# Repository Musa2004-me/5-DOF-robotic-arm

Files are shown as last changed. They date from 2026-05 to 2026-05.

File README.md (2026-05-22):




https://github.com/user-attachments/assets/d4726c3b-9be9-457d-948b-c11e2f1f0353



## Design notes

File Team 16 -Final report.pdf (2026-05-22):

# AIN SHAMS UNIVERSITY-FACULTY OF ENGINEERING

# [MCT343]

# Mechatronic System Design

# Final Submission Report

# Team 16

Name | ID | Section
Abdullah Mahmoud Abdelkarim | 2100658 | 1 MCT
Abdelkarim Wael Abdelkarim | 2101733 | 1 MCT
Mohamed Islam Salah Aldin Bodour | 2101439 | 1 MCT
Musa Gamal El-Shenawy | 2100614 | 1 MCT
Zeyad Samer Lotfy | 2100820 | 1 MCT

# Provided to:

# Mohamed Nabil Mohamed Mohamed (https://eng.asu.edu.eg/staff/m.nabil) Nansy Emad Mohamed Elhady (https://eng.asu.edu.eg/staff/nancy_emad)

# Contribution Sheet

Name | Contribution
Abdullah Mahmoud Abdelkarim | Actuator Sizing PID Design
Abdelkarim Wael Abdelkarim | Control Design PID Stress Analysis
Mohamed Islam Salah Aldin Bodour | Machine vision Design Report
Musa Gamal El-Shenawy | Design Report Simulation Actuator Sizing
Zeyad Samer Lotfy | Control Design PID

# Table of Contents

# Table of Figueres

# Introduction

In modern industrial automation, the need for efficient and accurate inspection systems has become very important to ensure high-quality standards. In line with this demand, a 5 Degree of Freedom (DOF) robotic arm has been designed and developed with the primary purpose of scanning products and detecting defects through QR code identification. This system is engineered to enhance the speed and reliability of product inspection processes, minimizing human error and increasing production efficiency.
The robot features five revolute joints, allowing it to achieve flexible and precise movements necessary to navigate various inspection points. Equipped with a high-resolution camera, the robotic arm locates and scans QR codes placed on different sections of the product. Each QR code contains essential data regarding the product's status, including defect information, manufacturing details, and quality control metrics. By decoding these QR codes, the robot swiftly determines if defects are present, categorizes the type of defect, and logs the inspection results for further processing.
The system is designed to operate seamlessly within industrial environments, capable of integrating with conveyor systems or stationary product lines. Its efficient path planning and real-time decision-making allow for rapid inspections, enhancing overall productivity. Furthermore, the robotic arm is programmed with advanced kinematic control, enabling it to reach complex product orientations with high accuracy.

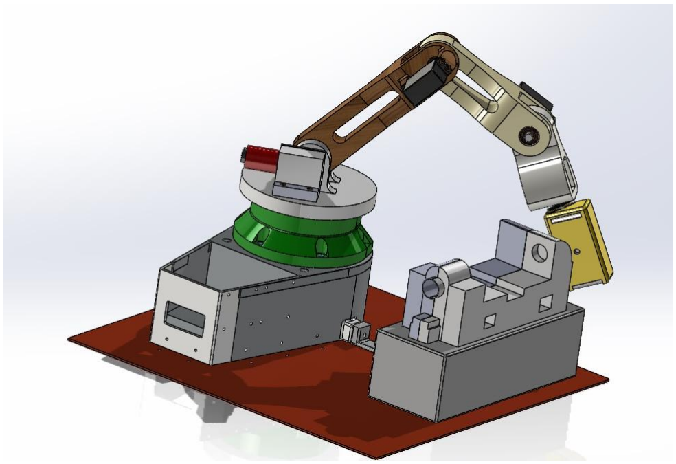
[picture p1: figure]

## Figure 1 5DOF Robotic Arm

# Design methodology and requirements analysis:

# We consider several parameters in our robotic arm:

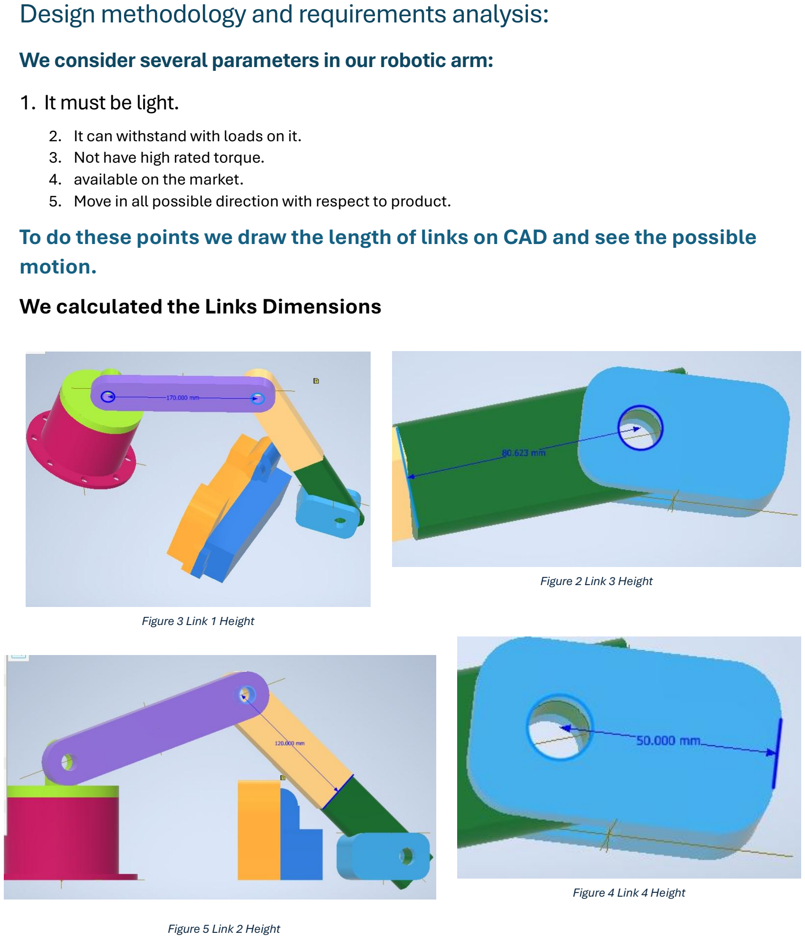
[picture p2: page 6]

1. It must be light.
2. It can withstand with loads on it.
3. Not have high rated torque.
4. available on the market.
5. Move in all possible direction with respect to product.

# To do these points we draw the length of links on CAD and see the possible

motion.

# We calculated the Links Dimensions

## Figure 3 Link 1 Height

## Figure 5 Link 2 Height

## Figure 2 Link 3 Height

## Figure 4 Link 4 Height

# Mechanical design specifications and CAD drawings

# Working Drawing:-

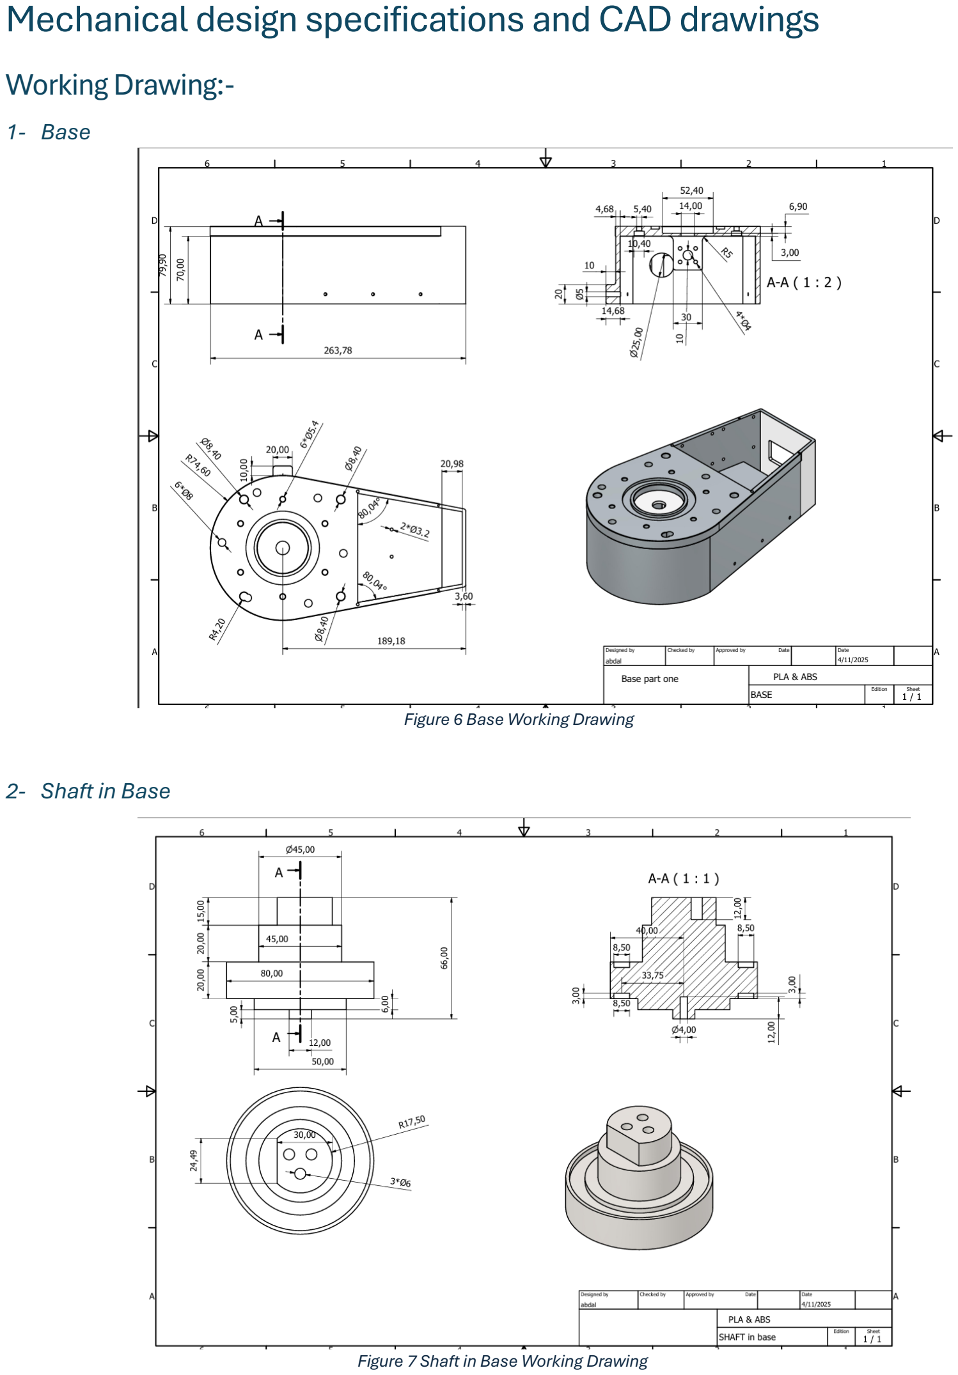
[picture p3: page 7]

# 1- Base

# 2- Shaft in Base

## Figure 6 Base Working Drawing

## Figure 7 Shaft in Base Working Drawing

# 3- Rotating Plate

# 4- Housing

## Figure 8 Rotating Plate Working Drawing

## Figure 9 Housing Working Drawing

# 5- Link 1

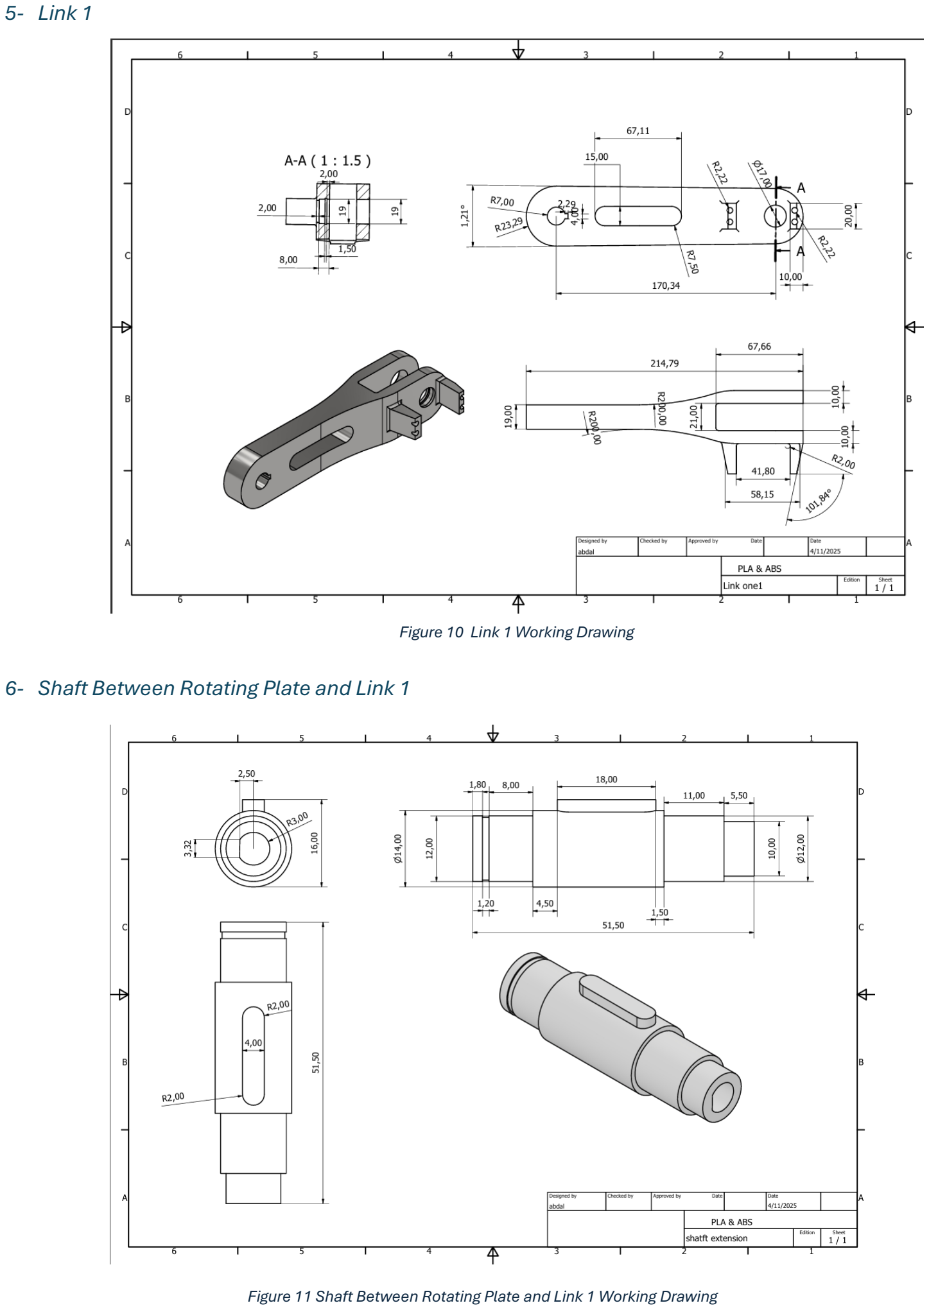
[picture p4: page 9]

# 6- Shaft Between Rotating Plate and Link 1

## Figure 10 Link 1 Working Drawing

## Figure 11 Shaft Between Rotating Plate and Link 1 Working Drawing

# 7- Link 2

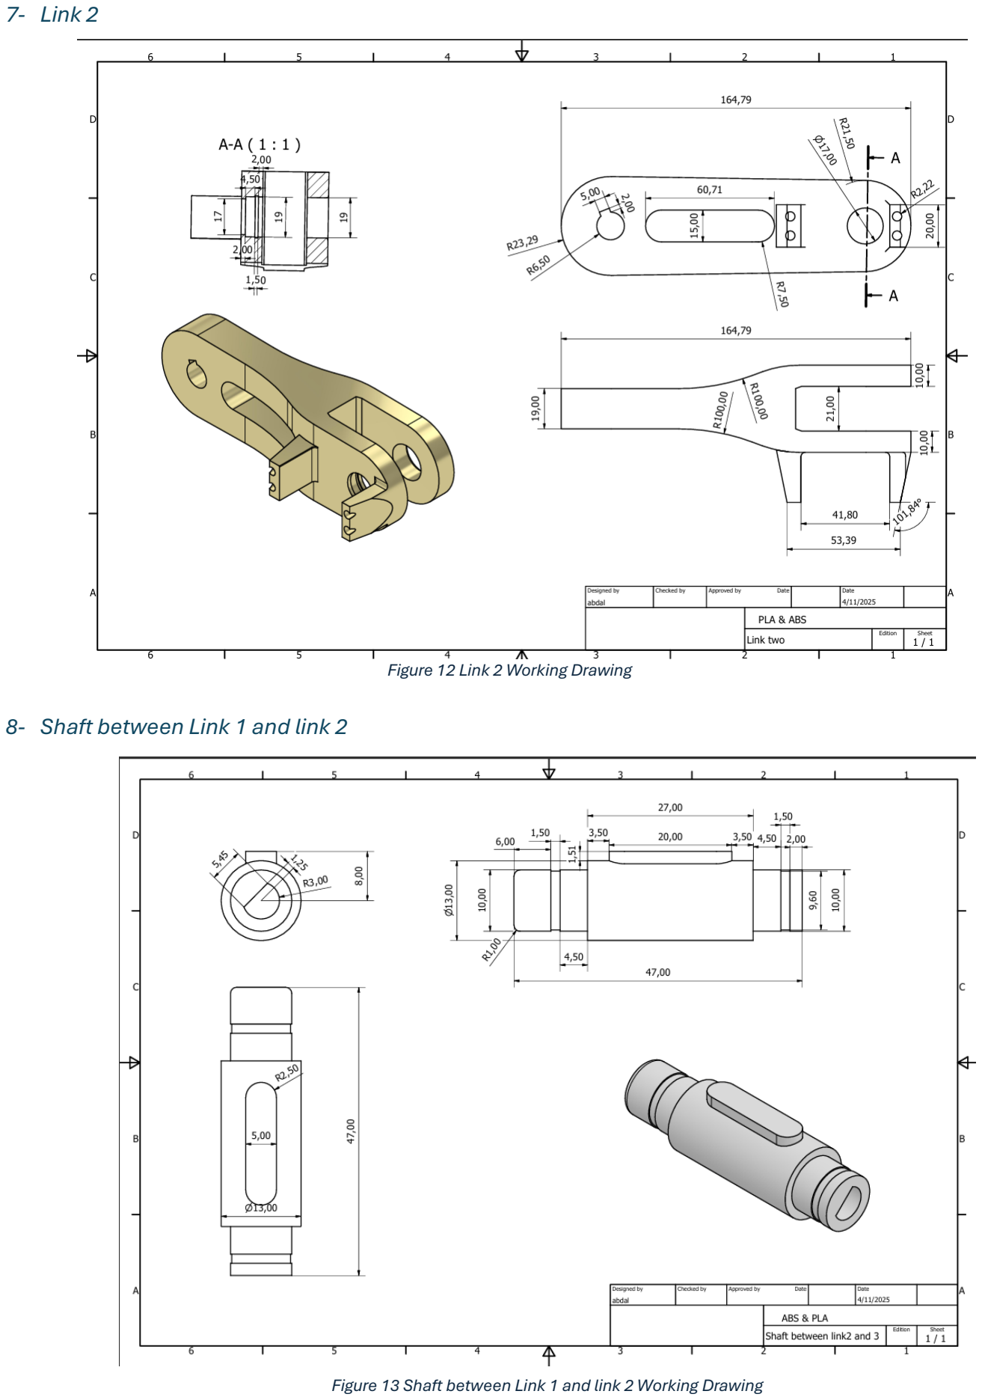
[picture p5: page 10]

# 8- Shaft between Link 1 and link 2

## Figure 12 Link 2 Working Drawing

## Figure 13 Shaft between Link 1 and link 2 Working Drawing

# 9- Link 3

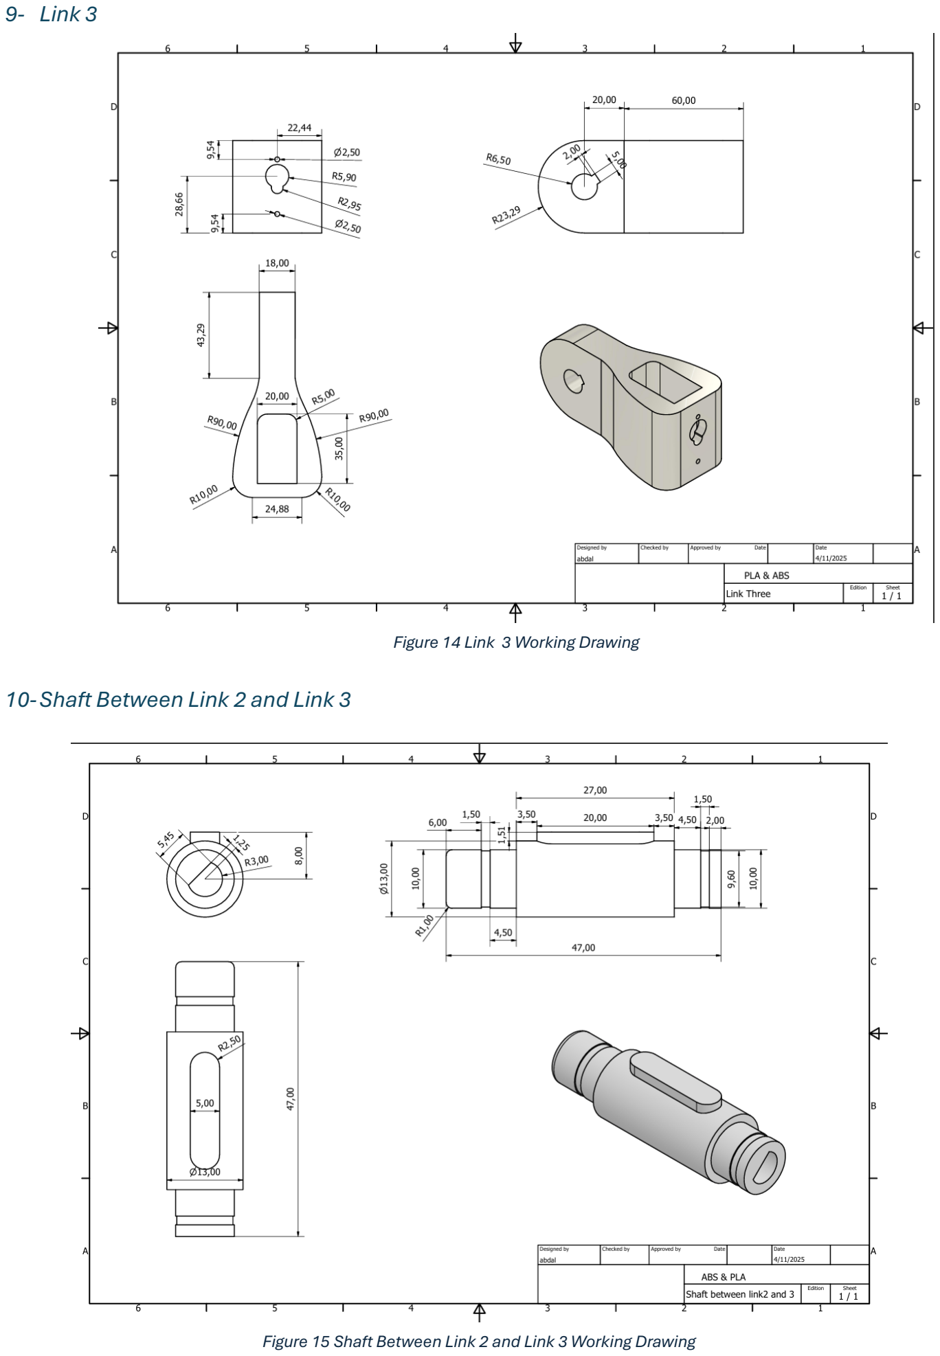
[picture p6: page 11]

# 10-Shaft Between Link 2 and Link 3

## Figure 14 Link 3 Working Drawing

## Figure 15 Shaft Between Link 2 and Link 3 Working Drawing

# 11-Camera Holder

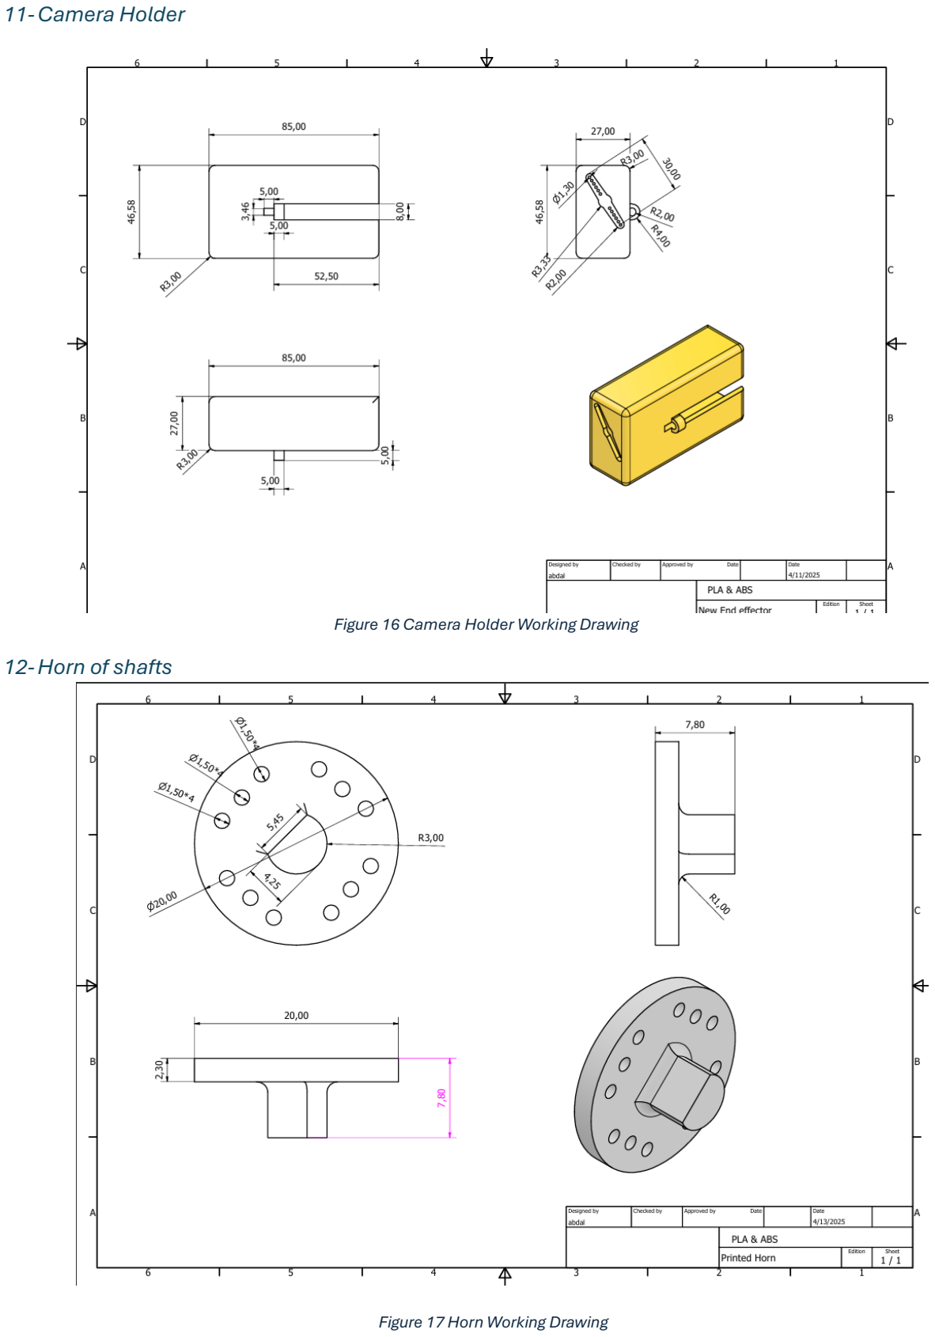
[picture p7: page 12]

# 12-Horn of shafts

## Figure 16 Camera Holder Working Drawing

## Figure 17 Horn Working Drawing

# Product

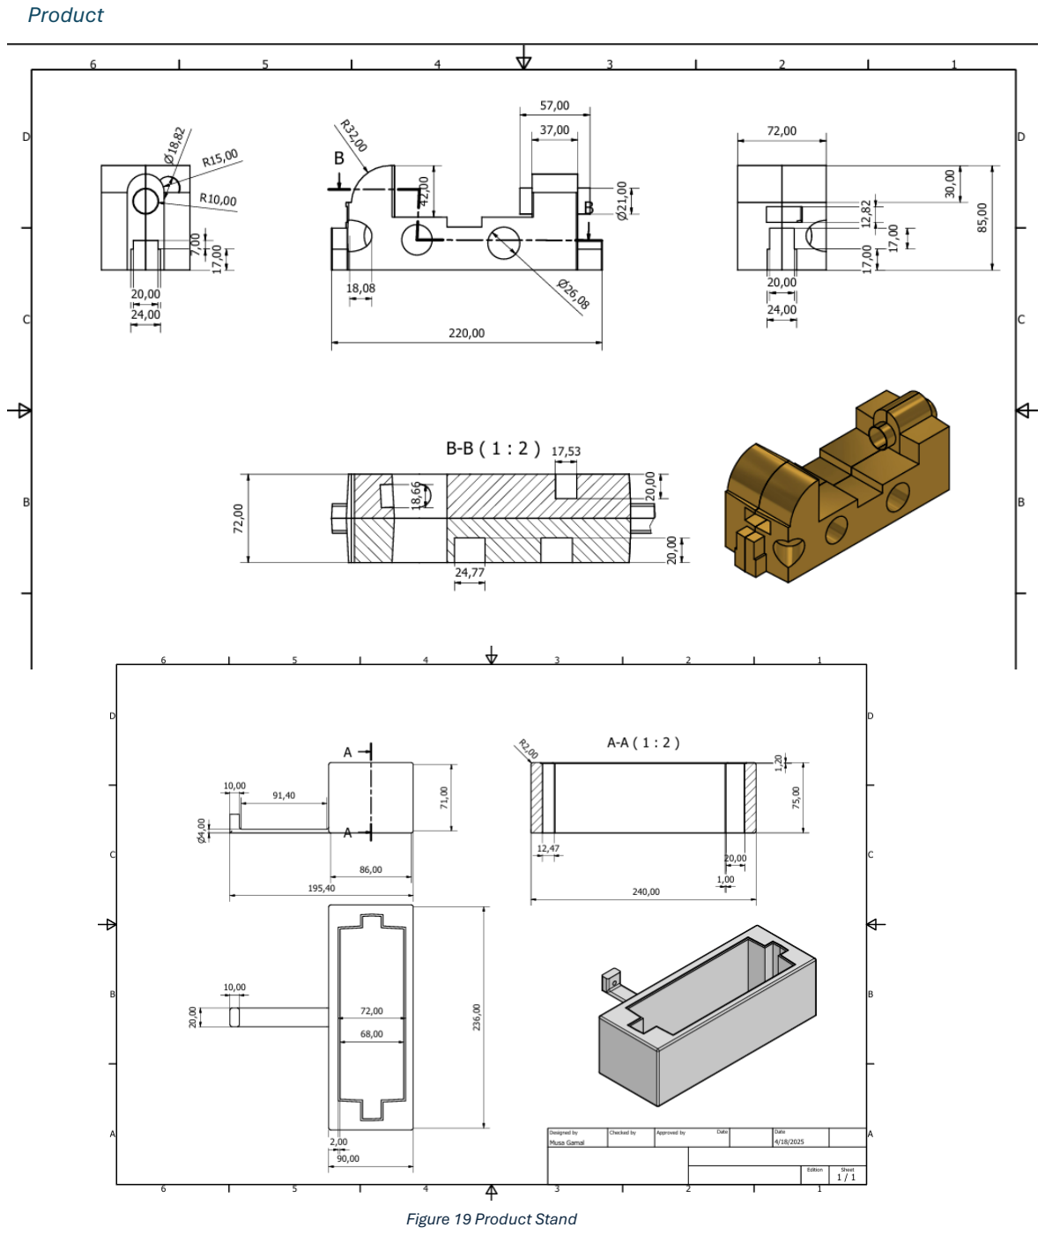
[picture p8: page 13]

# Product Stand

## Figure 18 Product Working Drawing

## Figure 19 Product Stand

# Assembly

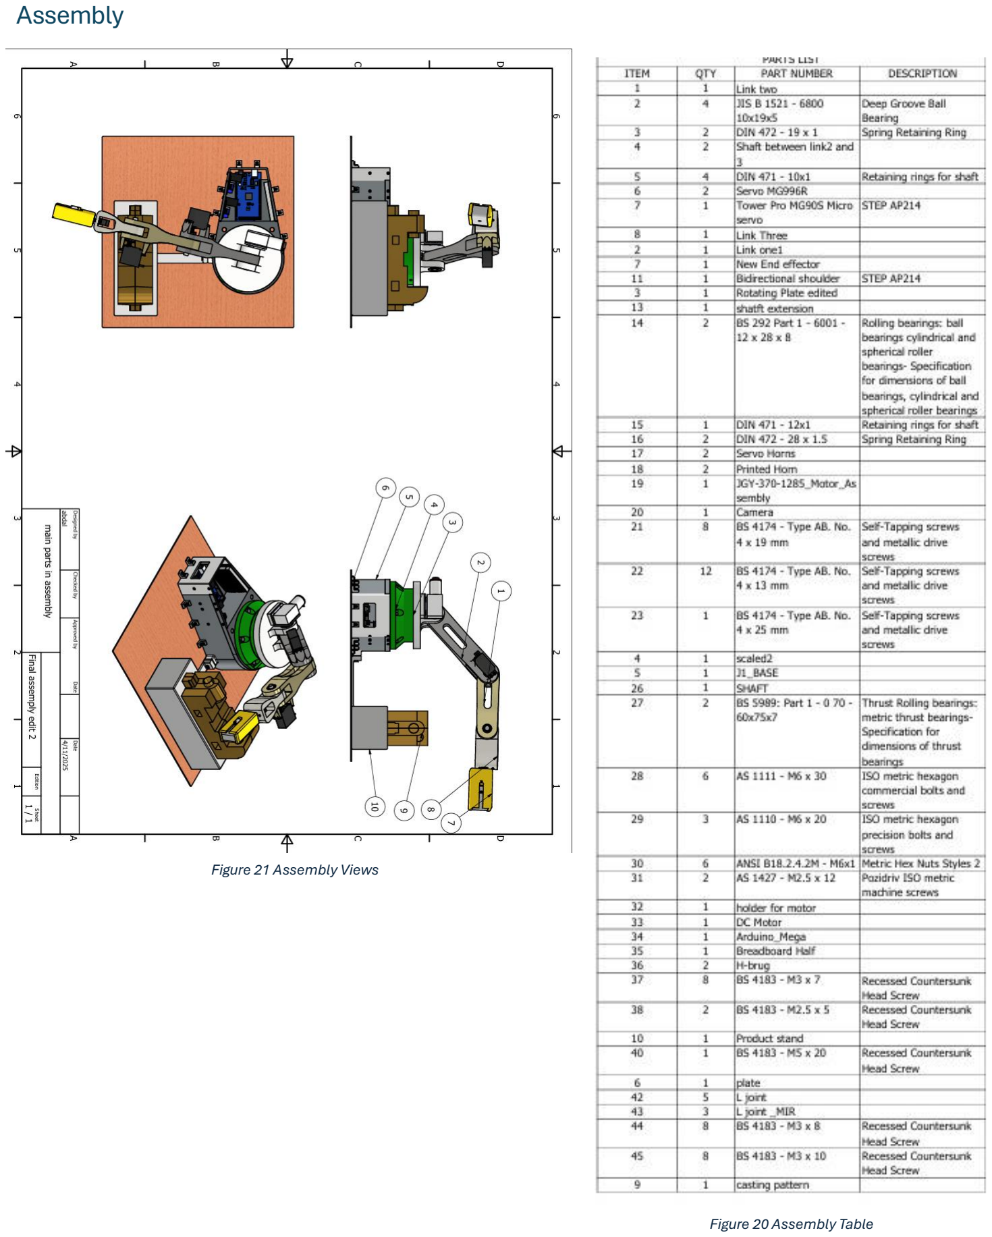
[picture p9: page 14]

## Figure 21 Assembly Views

## Figure 20 Assembly Table

# Links Connection

# Rotating plate & link 1 Connection

# Rotating plate & Base Connection

## Figure 22 Rotating plate & link 1 Connection

## Figure 23 Rotating plate & Base Connection

# Link 1 & link 2 Connection

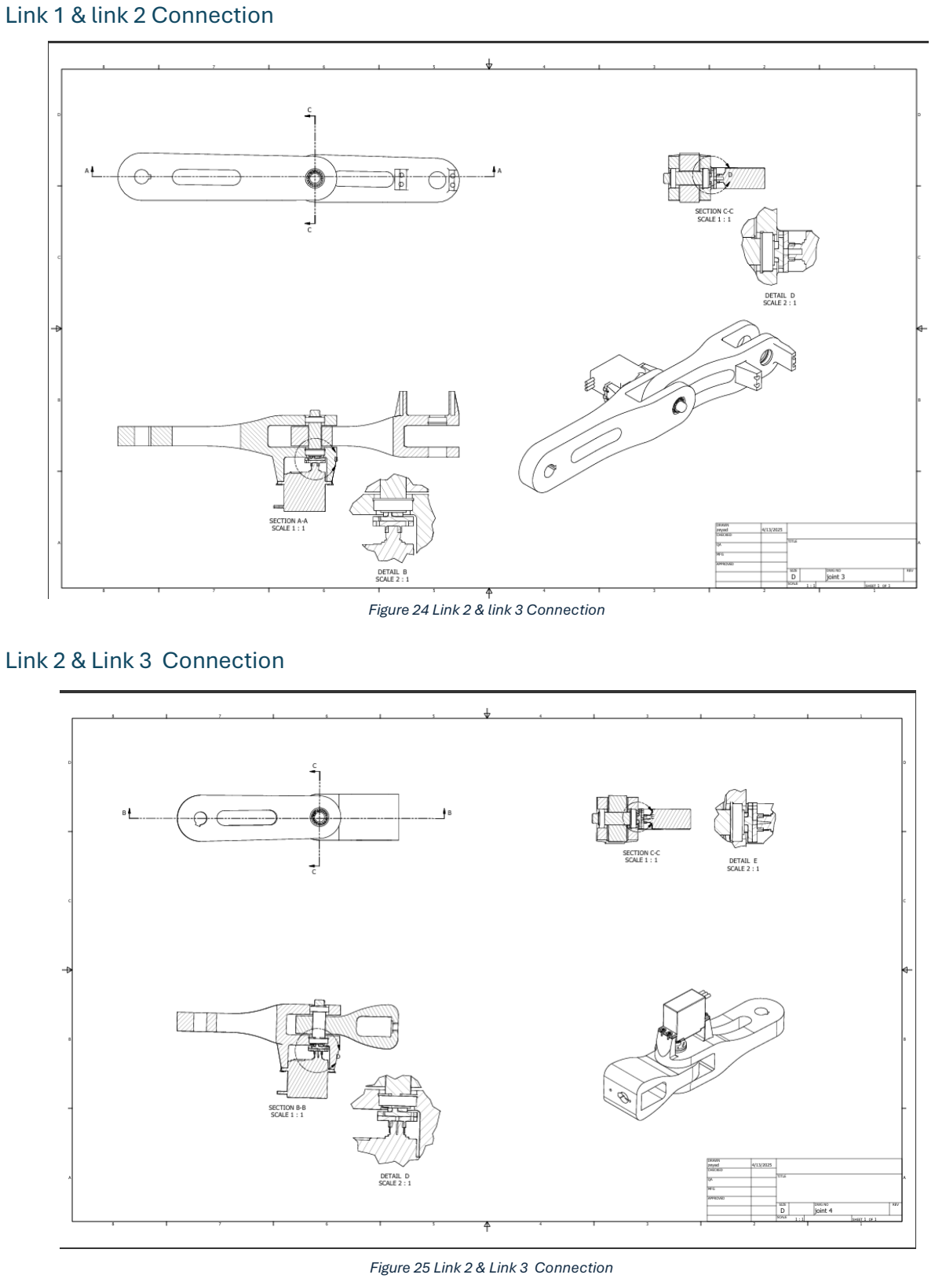
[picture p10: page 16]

# Link 2 & Link 3 Connection

## Figure 24 Link 2 & link 3 Connection

## Figure 25 Link 2 & Link 3 Connection

# Link 3 and camera holder Connection

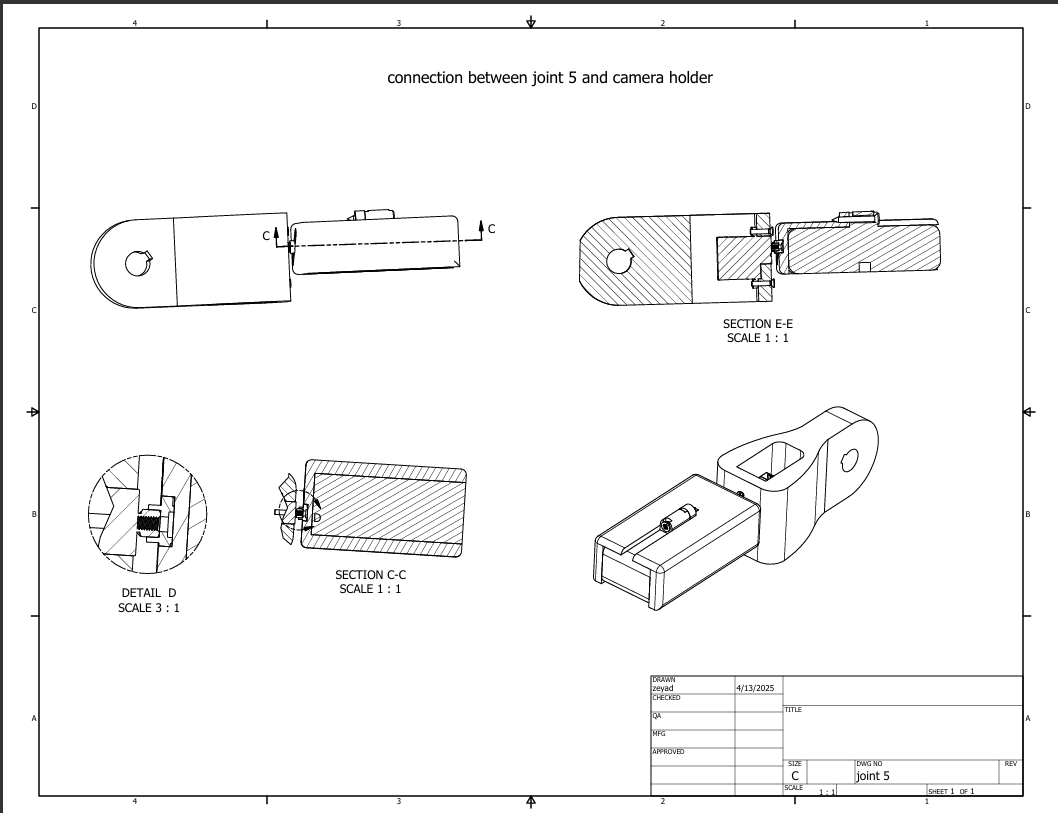
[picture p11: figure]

# Standard Parts :-

# 1) Bearing

# - 5989 thrust Bearing 60x75x7 - 6800 Ball Bearing 10x19x5 - 6001 Deep Groove Ball Bearing 12x28x8

# 2) Snap Ring

# - DIN 472 28x1.5 - DIN 472 19x1 - DIN 471 12x1 - DIN 471 10x1

# 3) Servo Horn, Bidirctional Arm of Servo

# 4) M3,M4,M5,M6,M8 Through Bolts

## Figure 26 Link 3 and camera holder Connection

# Stress Analysis:-

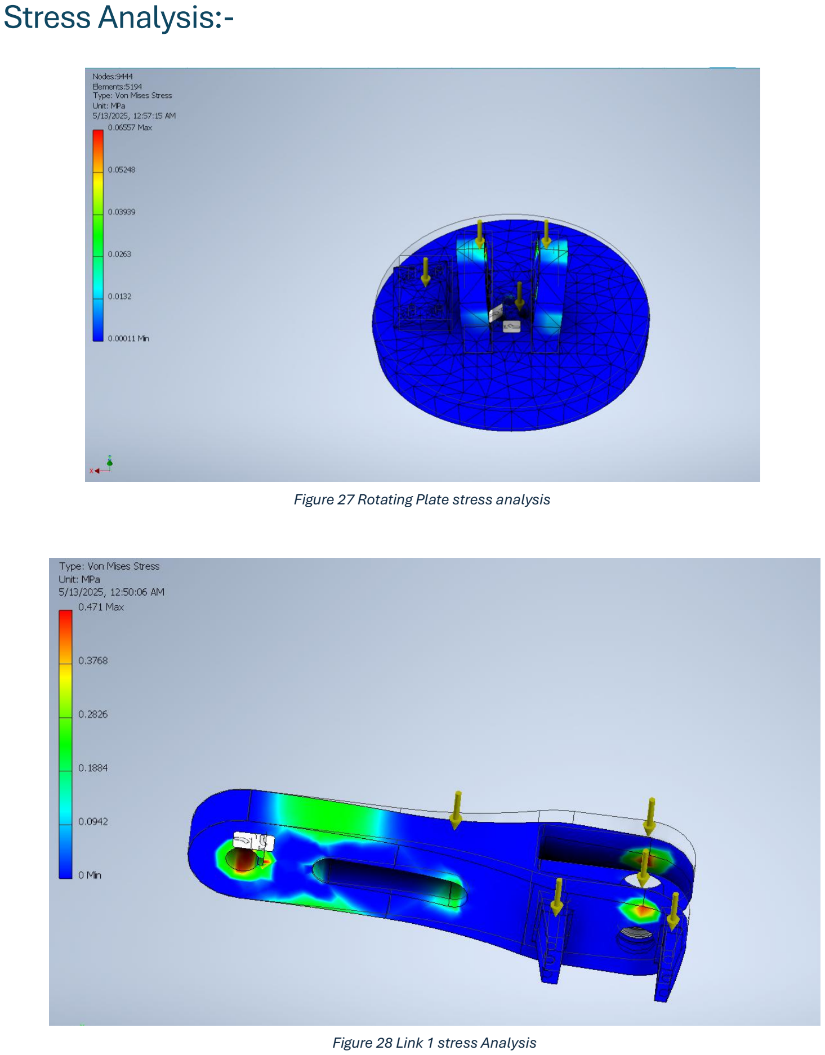
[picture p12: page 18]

## Figure 28 Link 1 stress Analysis

## Figure 27 Rotating Plate stress analysis

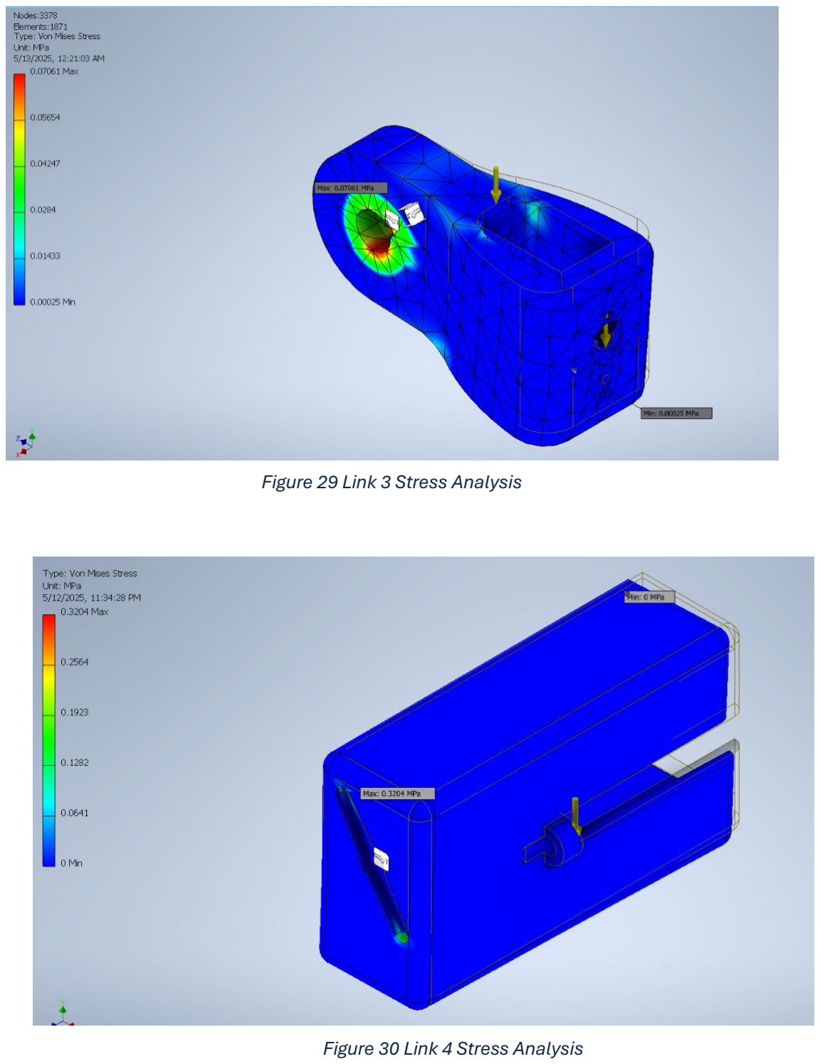
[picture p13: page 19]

## Figure 29 Link 3 Stress Analysis

## Figure 30 Link 4 Stress Analysis

# Shafts

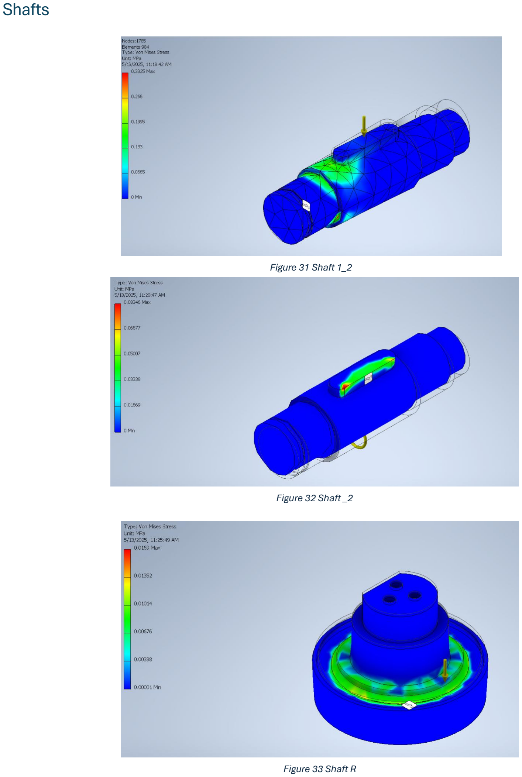
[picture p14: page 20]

## Figure 31 Shaft 1_2

## Figure 32 Shaft _2

## Figure 33 Shaft R

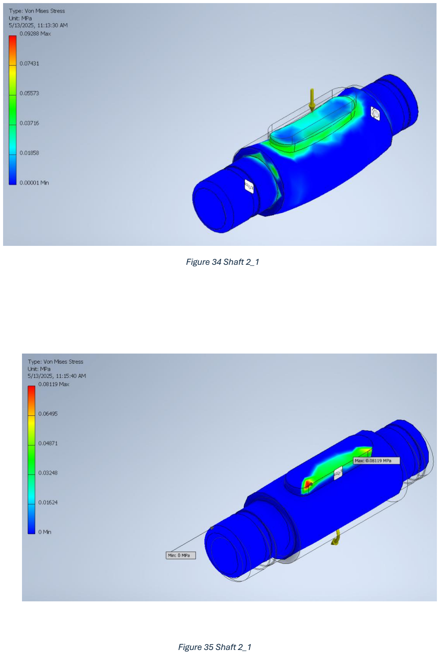
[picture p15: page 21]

## Figure 34 Shaft 2_1

## Figure 35 Shaft 2_1

## Figure 36 Shaft2_3

## Figure 37 Shaft2_3

# Actuator Sizing

# MATLAB-Simulink Model

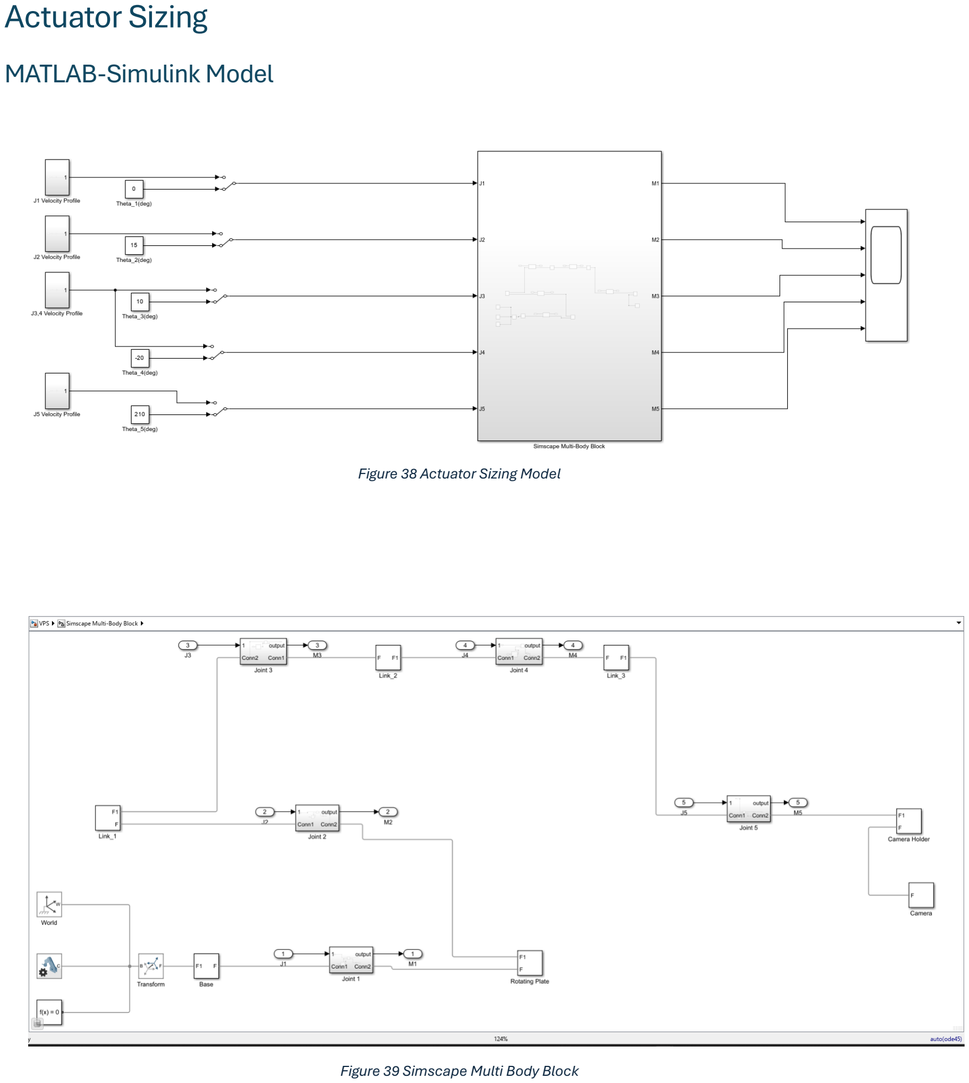
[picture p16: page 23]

## Figure 38 Actuator Sizing Model

## Figure 39 Simscape Multi Body Block

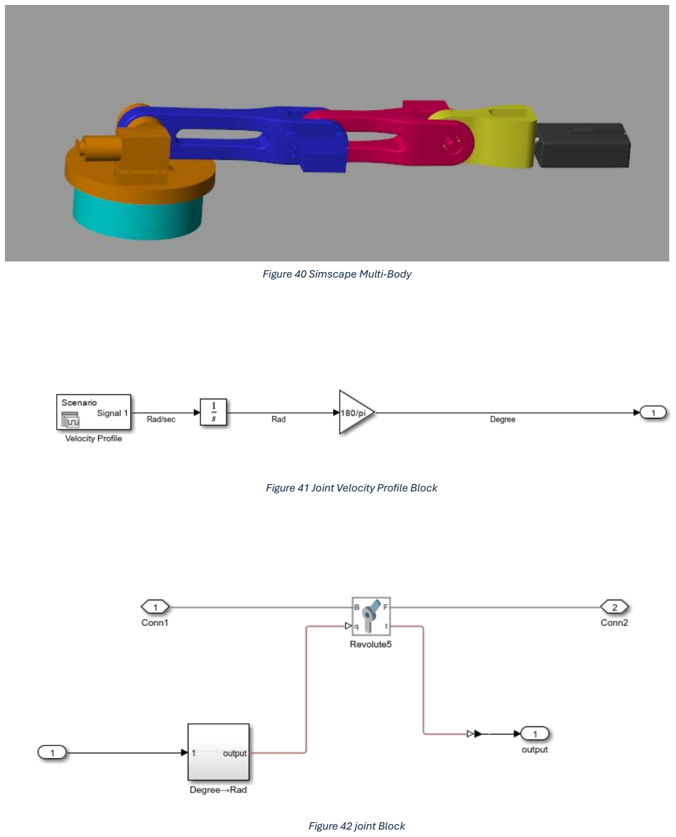
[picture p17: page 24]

## Figure 40 Simscape Multi-Body

## Figure 41 Joint Velocity Profile Block

## Figure 42 joint Block

# Actuator Torque on:-

# Joint 1

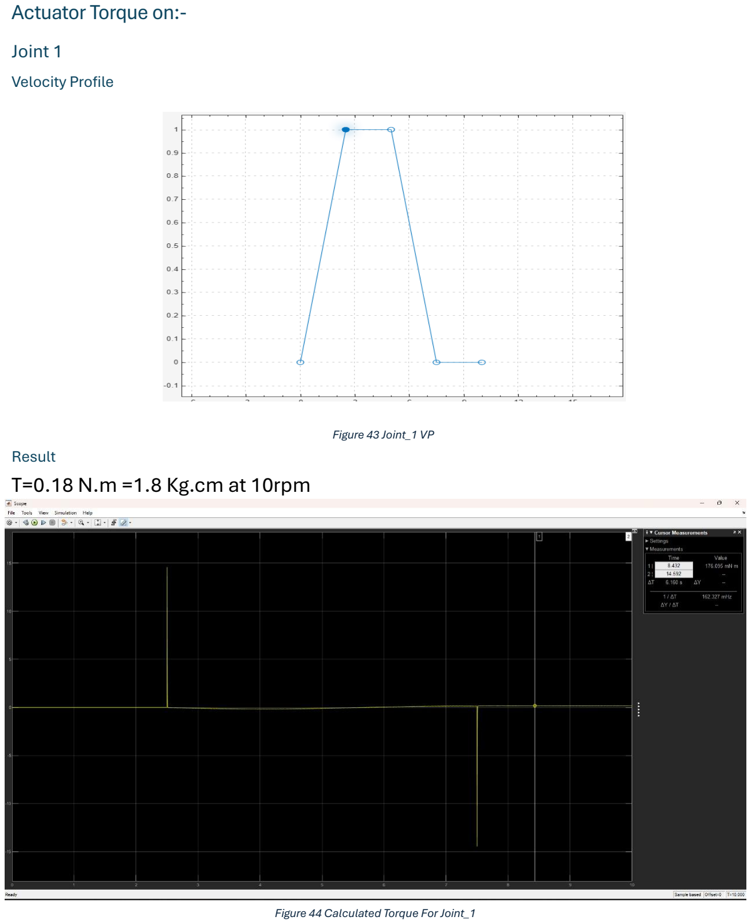
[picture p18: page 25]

# Velocity Profile

# Result

# T=0.18 N.m =1.8 Kg.cm at 10rpm

## Figure 43 Joint_1 VP

## Figure 44 Calculated Torque For Joint_1

# Joint 2

# Velocity Profile

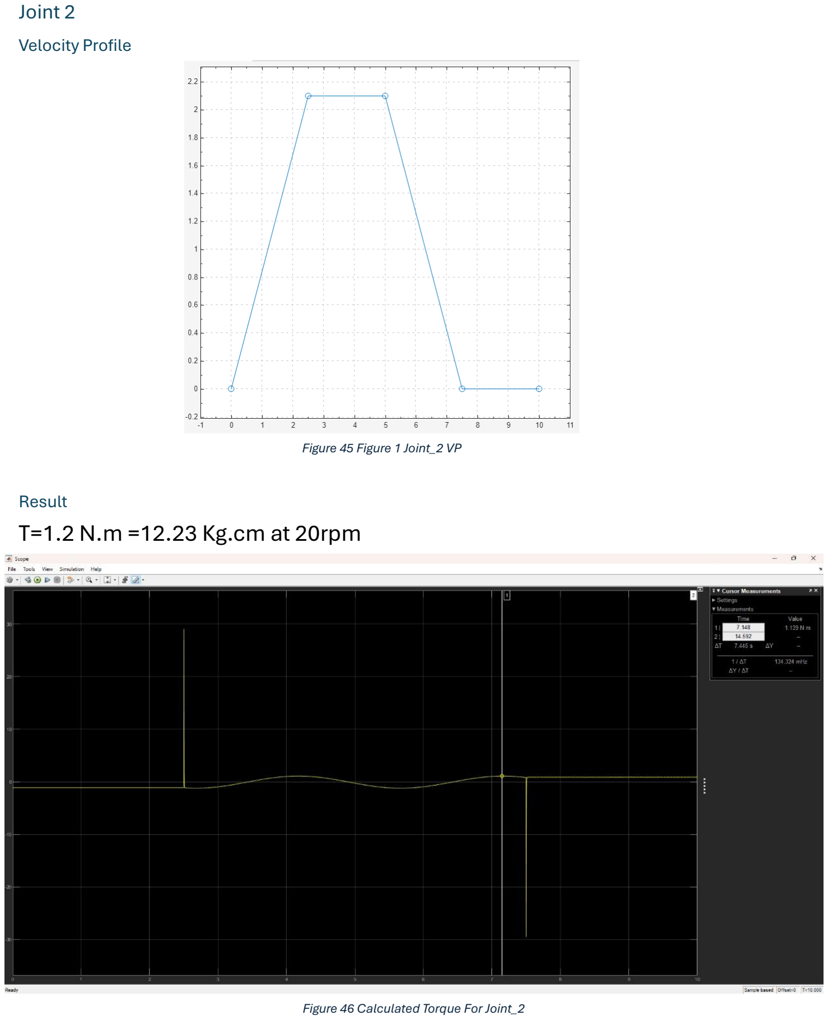
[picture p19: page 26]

# Result

# T=1.2 N.m =12.23 Kg.cm at 20rpm

## Figure 46 Calculated Torque For Joint_2

## Figure 45 Figure 1 Joint_2 VP

# Joint 3

# Velocity Profile

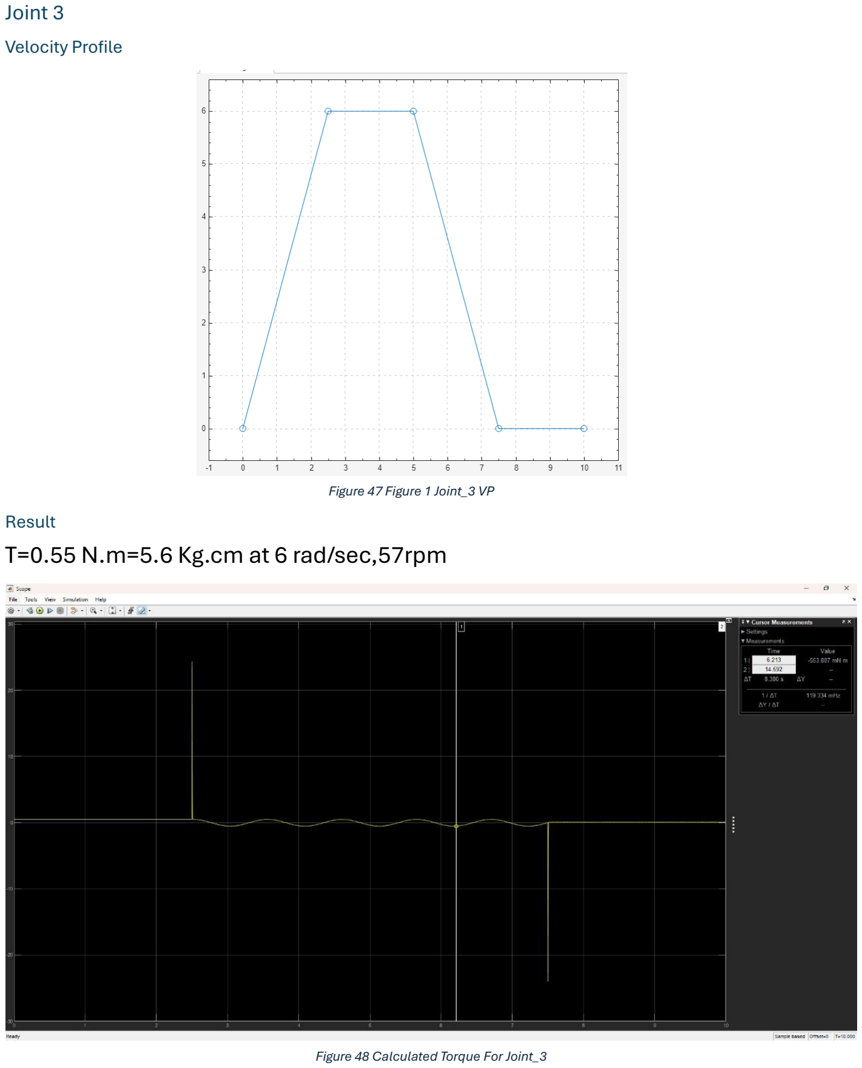
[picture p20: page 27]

# Result

# T=0.55 N.m=5.6 Kg.cm at 6 rad/sec,57rpm

## Figure 48 Calculated Torque For Joint_3

## Figure 47 Figure 1 Joint_3 VP

# Joint 4

# Velocity Profile

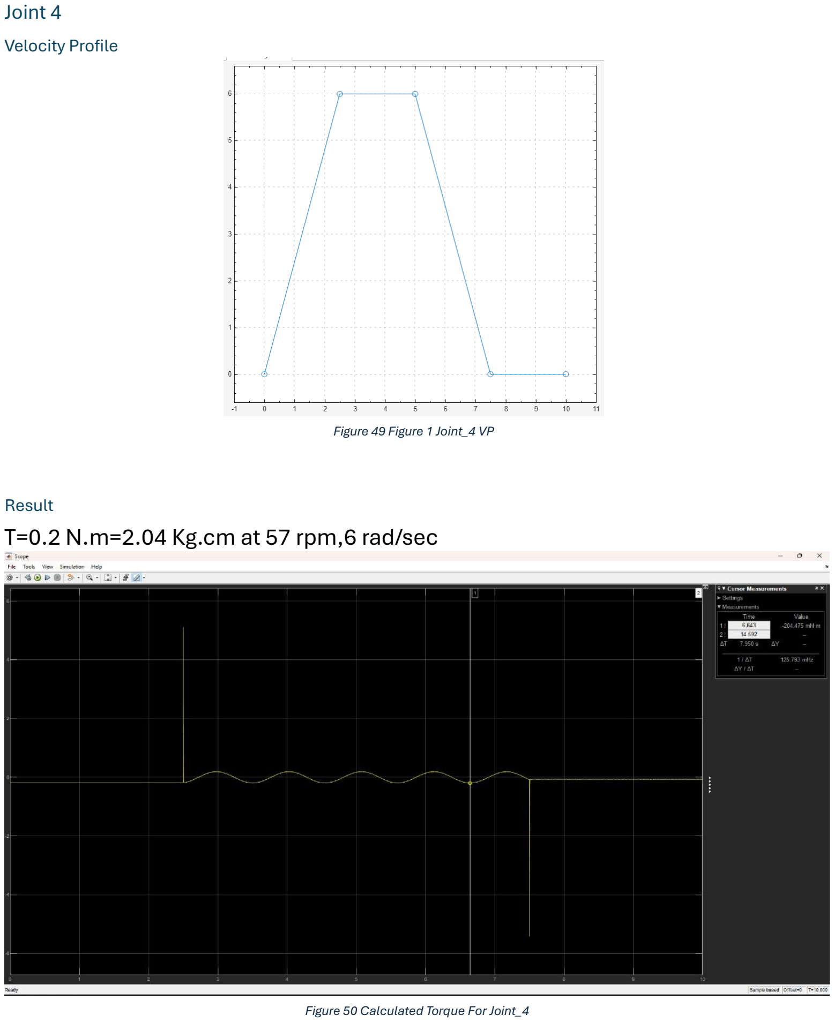
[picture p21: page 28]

# Result

# T=0.2 N.m=2.04 Kg.cm at 57 rpm,6 rad/sec

## Figure 50 Calculated Torque For Joint_4

## Figure 49 Figure 1 Joint_4 VP

# Joint 5

# Velocity Profile

# Result

# T= 0.0075N.m =0.076 Kg.cm at 10rad/sec,95.5 rpm

## Figure 52 Calculated Torque For Joint_5

## Figure 51 Figure 1 Joint_5 VP

# Actuator Selection:-

Joint | Actuator Torque(T)(Kg.cm) | Available Torque(Kg.cm) | Motor Type
1 | 1.8 | 4.4 | 25GA370 DC Gear Motor With Encoder
2 | 12.23 | 12.5 | JGY-370 DC Geared Motor With Encoder
3 | 5.6 | 10 | MG995 Servo Motor 180°
4 | 2.04 | 10 | MG996 Servo Motor 180°
5 | 0.075 | 3.2 | S3003 Servo Motor 270 Degree

# Electronics and control system documentation

This circuit is designed to control multiple motors and servos using an Arduino Mega 2560 microcontroller. It includes JGY-370 And JGA25-371 DC Geared motors with encoders, two MG996R servos, one MG90S servo, and an L298N motor driver. Power is supplied by a 12V adapter OR a 12V lithium-ion battery. A LM7805 MOSFET is used to control the power to the motor driver.

# Microcontroller Integration and Circuit Schematics

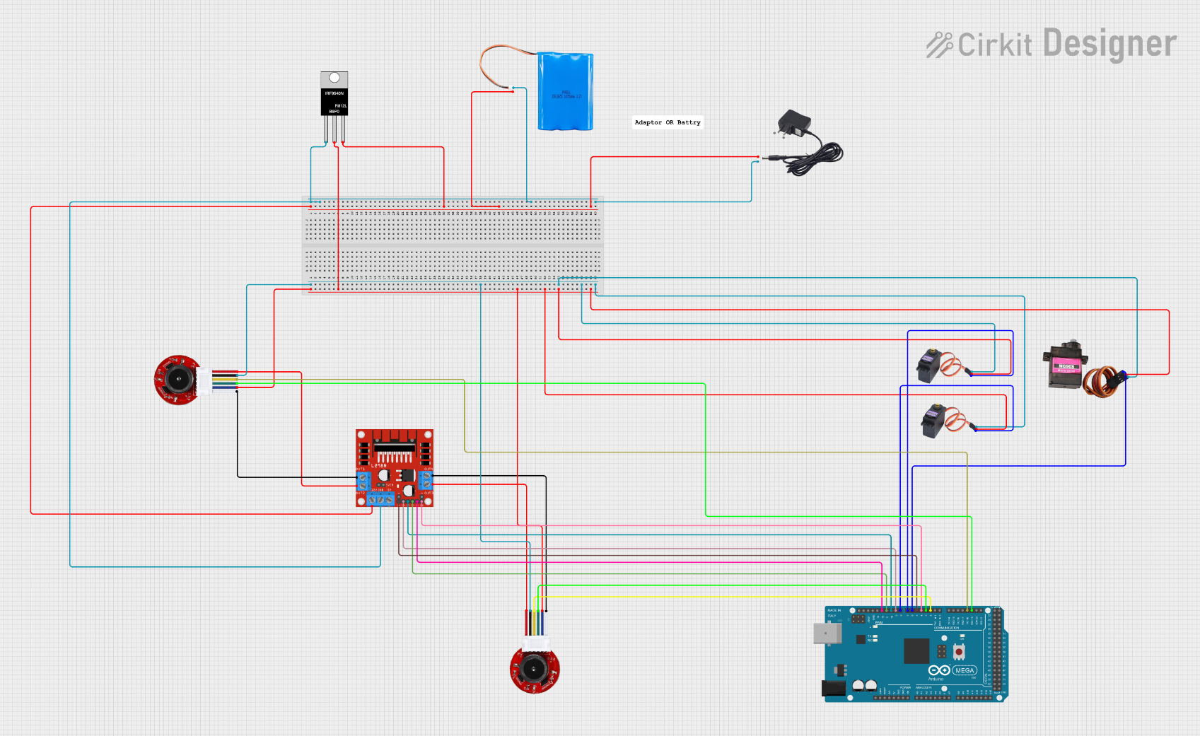
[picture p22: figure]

# FULL PIN MAPPING SUMMARY

Device | Arduino Pin
Motor A IN1/IN2 | D9, D10
Motor B IN3/IN4 | D11, D12
ENA/ENB (PWM) | D5, D4
Encoder A (motor A) | D2 (INT)
Encoder B (motor A) | D3
Encoder A (motor B) | D18 (INT)
Encoder B (motor B) | D19
Servo MG996R #1 | D6
Servo MG996R #2 | D7
Servo MG90S | D8

## Figure 53 Robot Motion Control System Circuit

# Hint:

# We use cytron MDD3A motor driver as we need linear

voltage to PWM relation and more delivered current.

# Battery Sizing

# Estimate Power Consumption

Component | Voltage (V) | Current (A) | Power (W) = V × I
25GA370 DC Gear Motor w/ Encoder | 12 | 1.2 | 14.4
JGY-370 DC Gear Motor w/ Encoder | 12 | 1.5 | 18
MG995 Servo Motor (180°) | 5 | 1 | 5
MG996 Servo Motor (180°) | 5 | 1 | 5
S3003 Servo Motor (270°) | 5 | 0.8 | 4
Arduino Mega | 12 | 0.1 | 1.2
Encoders (2x) | 5 | 0.05 | 0.5

# Total Power Consumption Total Power (W) =48.1 W Adjust for Efficiency Loss Assume Battery Efficiency (η) = 85% (0.85) Adjusted Power = Power / η = 48.1 / 0.85 ≈ 56.6 W Daily Energy Demand:-Daily Energy (Wh) = 56.6 × 1 = 56.6 Wh/day

# Battery Capacity (Ah)

=

## Daily Energy

Voltage = 56.6 / (12) = 4.71 Ah.

# Control Flowchart

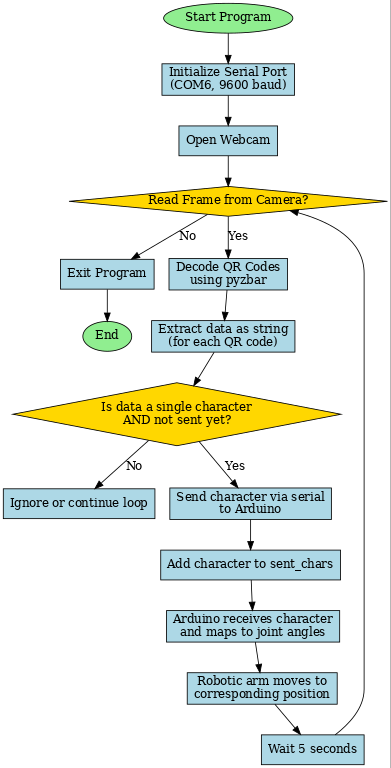
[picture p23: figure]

## Figure 54 FlowChart of contol the Arm

# DC Motor Position Control Using PID with Encoder Feedback

To control the position of two DC motors using a PID controller based on encoder feedback, ensuring stability, minimal overshoot, and accurate steady-state response.

# Experimental Procedure

# - System Initialization

# - Initial Testing

- Applied a step input (desired position) to the motors. Observed open-loop response: unstable, underdamped, high overshoot, and slow settling.

# - Tuning Method: Trial and Error

- Started with all PID gains set to zero.

# - Increased Kp incrementally:

- System started to respond to input but was unstable and oscillated.
- Increases speed of response.
- High Kp reduces rise time but causes overshoot.

# - Introduced Ki to eliminate steady-state error:

- Response improved over time.
- But too high Ki caused instability or integral windup.
- Eliminates steady-state error.

# - Added Kd to reduce oscillations:

- Improves stability and damping.
- Reduces overshoot and oscillation, but sensitive to noise.

# - Add LPF filter:

- Filters high-frequency noise in encoder signal to prevent noisy derivative action.

# Final PID Parameters

The best performance (minimal overshoot, fast response, and zero steady-state error) was achieved with the

# following values:

- Underdamped response with acceptable overshoot (~5–10%).
- Settling time decreased significantly.
- Proper tuning of PID gains significantly improved control performance.
- The trial-and-error approach was effective but time-consuming.

# Simulink Implementation using Simscape library:-Simscape Multibody Model:-

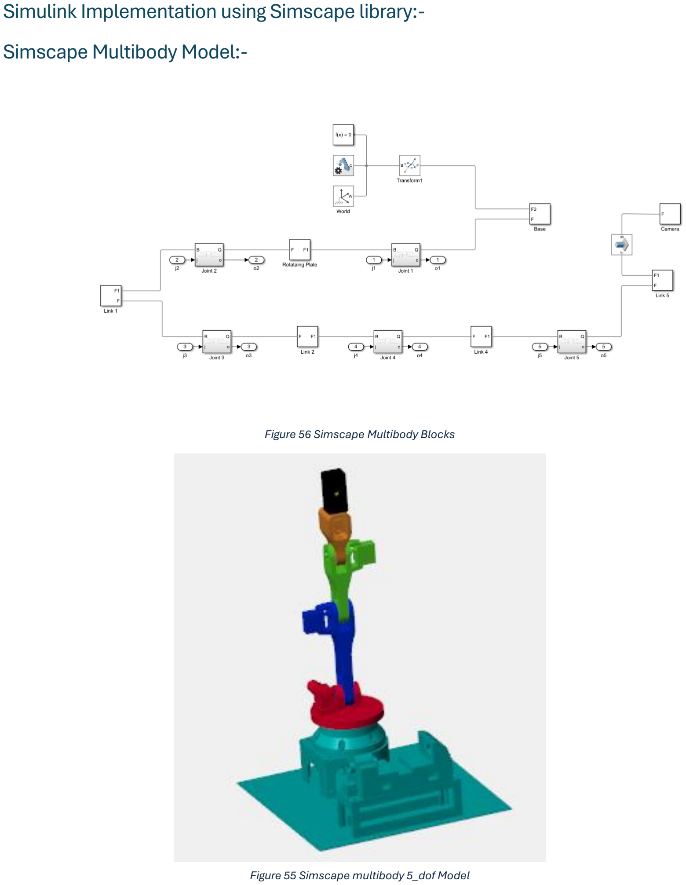
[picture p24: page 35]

## Figure 56 Simscape Multibody Blocks

## Figure 55 Simscape multibody 5_dof Model

# Limitations, challenges, and recommendations for improvement:

# Limitation:

1- Mony and time.

# 2- Trial to make bast Hardware 3- Gain information in a limited time

# challenges:

# 1- Some changing in hardware due to ware our fracture

2- Dealing with some new objects in same time.

# 3- Gain information in a limited time

# Improvement:

1- Changing material to metal.

2- Change some parameter in design 3- Chang design to be more flexible and easier to assembly 4- Select Motor with high Torque with an encoder 5- Change the controller to higher version like PLC,Teensy4.1,Esp32 6- Use ROS for better performance and control 7- Organize the code and make it work professionally

# Drive Link For All CAD and MATLAB Files:-

# https://drive.google.com/drive/folders/1w6MkZo-5VQtZ7_8EzhHSHovvDaRskz3O?usp=sharing

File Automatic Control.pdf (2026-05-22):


# AIN SHAMS UNIVERSITY-FACULTY OF ENGINEERING

# [MCT211s]

# Automatic Control

# Final Submission Report

# Team 16

Name | ID | Section
Abdullah Mahmoud Abdelkarim | 2100658 | 1 MCT
Abdelkarim Wael Abdelkarim | 2101733 | 1 MCT
Mohamed Islam Salah Aldin Bodour | 2101439 | 1 MCT
Musa Gamal El-Shenawy | 2100614 | 1 MCT
Zeyad Samer Lotfy | 2100820 | 1 MCT

## Provided to:

# Dr. Diaa Emad Abdel Fattah Mohamed (https://eng.asu.edu.eg/staff/diaa.emad)

# Table of Contents

# Table Of Figures

# Introduction

Precise motion control is a cornerstone of modern automation, robotics, and mechatronic systems. This project focuses on the development and implementation of a 2 Degree-of-Freedom (2-DOF) mechanism designed to achieve accurate position and speed control through a closed-loop feedback system. Leveraging the power of MATLAB/Simulink along with microcontroller programming support packages, this project integrates simulation and physical implementation to bridge theoretical control design with real-world

performance.

The system is designed to utilize PID (Proportional-Integral-Derivative) control algorithms, which are tuned for both position and velocity regulation. The control design is iteratively tested through simulations, allowing for the evaluation and refinement of controller parameters based on response characteristics such as rise time, settling time, steady-state error, and stability under varying operational

conditions.

# Following successful simulation, the controller is deployed to a physical model

using a microcontroller, enabling real-time execution of the control logic.

# Performance of the physical system is then compared to the simulation results to validate accuracy and effectiveness. This comprehensive approach provides valuable insights into the design, tuning, and real-world implementation of

feedback-controlled mechanical systems.
Through this project, students gain hands-on experience with system modeling,

# controller design, dynamic simulation, and embedded implementation—key

competencies in control systems engineering.

# Block diagram For the System


# System Components:

# - Set Point

# - This is the desired angular position (Theta) input, typically a step input in

control systems.

# - Outer Loop: Position Control

# - Error = Set Point - Theta: The difference between the desired and actual

position.

# - Controller_1 (PID(s)): A PID controller that generates a velocity command

(w) based on the position error.

# - Inner Loop: Velocity Control

- Error : The difference between the desired velocity and the actual velocity.

# - Controller_2 (PID(s)): Another PID controller that generates a control signal

(voltage) for the plant based on velocity error.

# - Plant Transfer Function

- Represents the physical system or plant (e.g., a DC motor).
- Takes in voltage and outputs angular velocity (ω).

# - Integrator (1/s)

- Integrates angular velocity (ω) to obtain angular position (Theta).

Figure 1 Block diagram For the System

# - Feedback Loops

# - Outer loop feedback: Theta is fed back to the first summing junction for

position error calculation.

# - Inner loop feedback: ω is fed back to the second summing junction for

velocity error calculation.

# Control Strategy This is a cascaded control architecture, where:

- The outer loop ensures position tracking (slower loop).
- The inner loop ensures velocity control (faster loop). This structure improves response time and robustness.

# System Model Using Simulink Block


# Set Point - Determine the set point(Rad) and convert it to degree

# Position - Reading the actual value of the position using encoder and convert the number of pulses to degrees

Figure 2 System Model Using Simulink Block

Figure 3 Set Point

Figure 4 Position Reading

# Velocity - convert the number of pulses to RPM


# Position Control By getting the error between the set point and the actual position, the PID convert

the error to the angular velocity desired.

# Velocity Control By getting the error between the angular velocity and the desired Velocity, the PID

convert the error to PWM voltage.

Figure 5 Velocity Reading

Figure 6 Position Control

Figure 7 Velocity Control

# Motor driver function - link the Arduino to the Simulink


Figure 8 Motor driver function Block

Figure 9 Motor driver function

# Simscape Model


# Electrical Subsystem

# PWM Signal Generator & H-Bridge Driver

- Top-left: A reference signal (ref+) and (ref−) is used to generate PWM.
- Drives an H-Bridge (DC-DC converter) for motor control.

# H-Bridge Block

- Receives PWM and control signals (REF, REV, BRK).
- Outputs a DC voltage to the motor circuit.
- This is the power electronics interface between controller and motor.

# Armature Circuit

# - Contains:

- Inductance (L): Motor armature inductance.
- Resistance (R): Armature winding resistance.
- Captures electrical dynamics of the motor.

# Voltage Sensor or Measurement Node

# - Positioned before connecting to the mechanical domain (torque

output).

Figure 10 Simscape model

# Mechanical Subsystem

# Rotational Mechanical Interface

# - Interface block connecting the electrical torque output to mechanical

motion.

# Equivalent Damping

- Models viscous friction or damping in the mechanical load.

# Equivalent Inertia

- Models rotational inertia of the motor and load.

# Rotational Motion Sensor

- Measures angular velocity or position.
- Feeds back to the controller for closed-loop control.

# This system simulates a realistic electromechanical model of a DC motor including switching behavior (PWM), physical components, and mechanical

dynamics.

# Electronics and control system documentation

This circuit is designed to control multiple motors and servos using an Arduino Mega 2560 microcontroller. It includes JGY-370 And JGA25-371 DC Geared motors with encoders, two MG996R servos, one MG90S servo, and an L298N motor driver. Power is supplied by a 12V adapter OR a 12V lithium-ion battery. A LM7805 MOSFET is used to control the power to the motor driver.

# Microcontroller Integration and Circuit Schematics


# FULL PIN MAPPING SUMMARY

Device | Arduino Pin
Motor A IN1/IN2 | D9, D10
Motor B IN3/IN4 | D11, D12
ENA/ENB (PWM) | D5, D4
Encoder A (motor A) | D2 (INT)
Encoder B (motor A) | D3
Encoder A (motor B) | D18 (INT)
Encoder B (motor B) | D19
Servo MG996R #1 | D6
Servo MG996R #2 | D7
Servo MG90S | D8

Figure 11 Robot Motion Control System Circuit

## Hint:

## We use cytron MDD3A motor driver as we need linear

voltage to PWM relation and more delivered current.

# DC Motor Position Control Using PID with Encoder Feedback

To control the position of two DC motors using a PID controller based on encoder feedback, ensuring stability, minimal overshoot, and accurate steady-state response.

# Experimental Procedure

# - System Initialization - Initial Testing

- Applied a step input (desired position) to the motors. Observed open-loop response: unstable, underdamped, high overshoot, and slow settling.

# - Tuning Method: Trial and Error

- Started with all PID gains set to zero.

## - Increased Kp incrementally:

- System started to respond to input but was unstable and oscillated.
- Increases speed of response.
- High Kp reduces rise time but causes overshoot.

## - Introduced Ki to eliminate steady-state error:

- Response improved over time.
- But too high Ki caused instability or integral windup.
- Eliminates steady-state error.

## - Added Kd to reduce oscillations:

- Improves stability and damping.
- Reduces overshoot and oscillation, but sensitive to noise.

# - Add LPF filter:

- Filters high-frequency noise in encoder signal to prevent noisy derivative action.

# Final PID Parameters

The best performance (minimal overshoot, fast response, and zero steady-state error) was achieved with the

## following values:

- Underdamped response with acceptable overshoot (~5–10%).
- Settling time decreased significantly.
- Proper tuning of PID gains significantly improved control performance.
- The trial-and-error approach was effective but time-consuming.

# Final Tuning Parameter

## Tuning For Motor 1

## Yellow : Actual position

## Red : Target

## Black: Control Action

- We designed the system with little overshoot for small friction in motion.


| Kp | Ki | Kd
M1 | 5 | 0.4 | 0.3
M2 | 2.2 | 0 | 0.8

Figure 12 Response of Motor 1


Figure 13 Response of Motor 1

Figure 14 Response of Motor 1


Figure 15 Response of Motor 2

Figure 16 Response of Motor 2


Figure 19 Response of Motor 2

Figure 17 Response of Motor 2

Figure 18 Response of Motor 2

# Mathematical Model of the System:-

# 1-Electrical equation:-

## Ea=(Ra+LS)Ia(s)+ Kbω

## Vin=Ea

# 2-Mechanical model

Figure 20 DC Motor Circuit

## Jω̇ = Tm −Tdamping −Tstatic → Neglecting initial condition(static torque)

## Tm =kt ×Ia(s)

## Tdamping = Beq × ω

## JeqS ω = kt× Ia(s)− Deq × ω

# Deq=Dm+Dmech.sys Jeq=Jm+Jmech.sys Transfer Function:-

ω
Vin =

1
R
Kt(S²Jeq + DeqS) + SKb

## → For simplicity we neglect L


Figure 21 Block Diagram Model Of The System

# Readings From the System

# A block diagram for Taking Reading from the real system


# - We made a voltage divider circuit to measure the voltage across the motor through the Arduino Analog pins - we divided the voltage across the motor by 3 to be able to measure it through the Arduino safely As max vin for pins =5 V

Figure 22 Block Diagram For Motor and Encoder

Figure 23 Voltage Divider Circuit

# Parameter Estimation Procedures : -

# -We need to make a parameter estimation for R,Kt,Kb,L,D and J -the system is 2DOF so we could Estimate 3 Parameter in 1 Experiment So we separate the Parameter estimation to 2 Steps :-1-Motor Estimation To estimate R , L , Kb,Kt ,D And J of the Motor

# Considering the energy conversion Pm=Tm ω=Pe=e ia→kT ia ω=ke ω ia kT=ke=k that’s why we assume that kT=ke=k - we take a 4 Readings from our system to estimate the R and K we solve it and it gives us R and K with an Error 3.64% From Equation Vin = RI+Ldi

dt

+kω

## At steady state Vin = RI+kω

# - From this Estimation we take R=4.8 ohm and K=0.5

K | R | Vin | current | N | ω | R I +kω | RI+kω-Vin | (RI+kω-Vin)² | ((RI+kω-Vin)/Vin)x100
0.499 | 4.8 | 10.3 | 0.1275 | 186 | 19.47787 | 10.35169 | 0.051691 | 0.002672 | 0.501857
| | 8 | 0.115 | 142 | 14.87021 | 7.98779 | -0.01221 | 0.000149 | -0.15262
| | 6 | 0.097 | 104 | 10.89085 | 5.911612 | -0.08839 | 0.007812 | -1.47314
| | 1.5 | 0.062 | 24 | 2.513274 | 1.554623 | 0.054623 | 0.002984 | 3.64153
| | | | | | | Sum | 0.013617

Figure 24 Estimation for R and K

# - We build motor Model at figure 16 To estimate L,D,J

Figure 25 Motor Model Subsystem

# From the Estimation with 10 iterations and validation we got that Dm= 0.0044698 N.m/(rad/s) L=4.38 mH Jm=0.0081555 Kg.m²

# Transfer function of the block:-


# Tunning

Figure 26 Transfer function of the block

Figure 27 Tuning Prameters

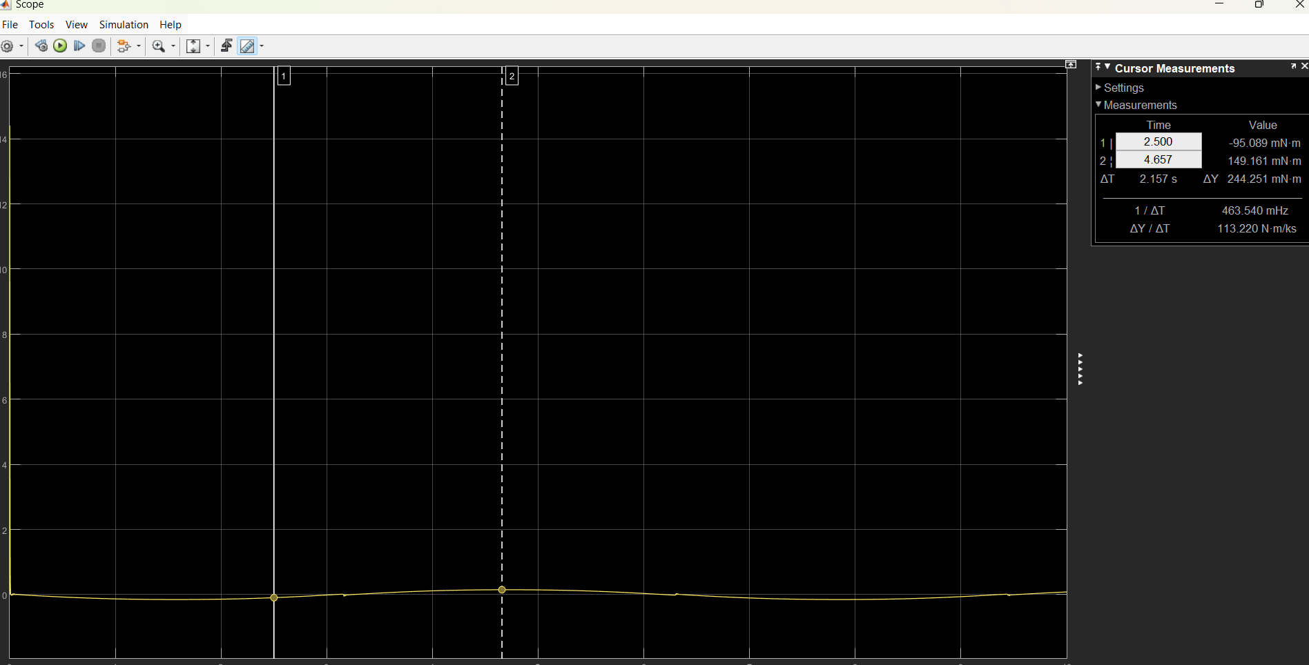
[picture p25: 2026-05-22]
matlab files/motor_1.png

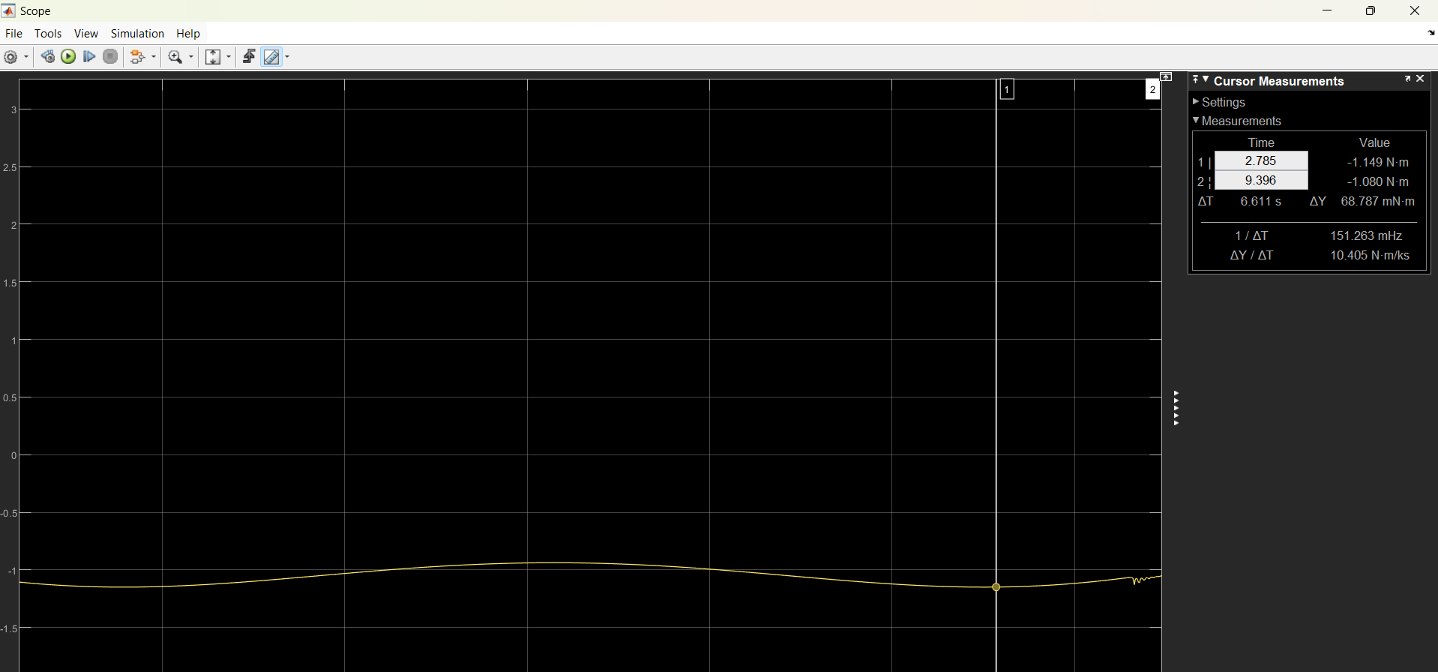
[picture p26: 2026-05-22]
matlab files/motor_2.png

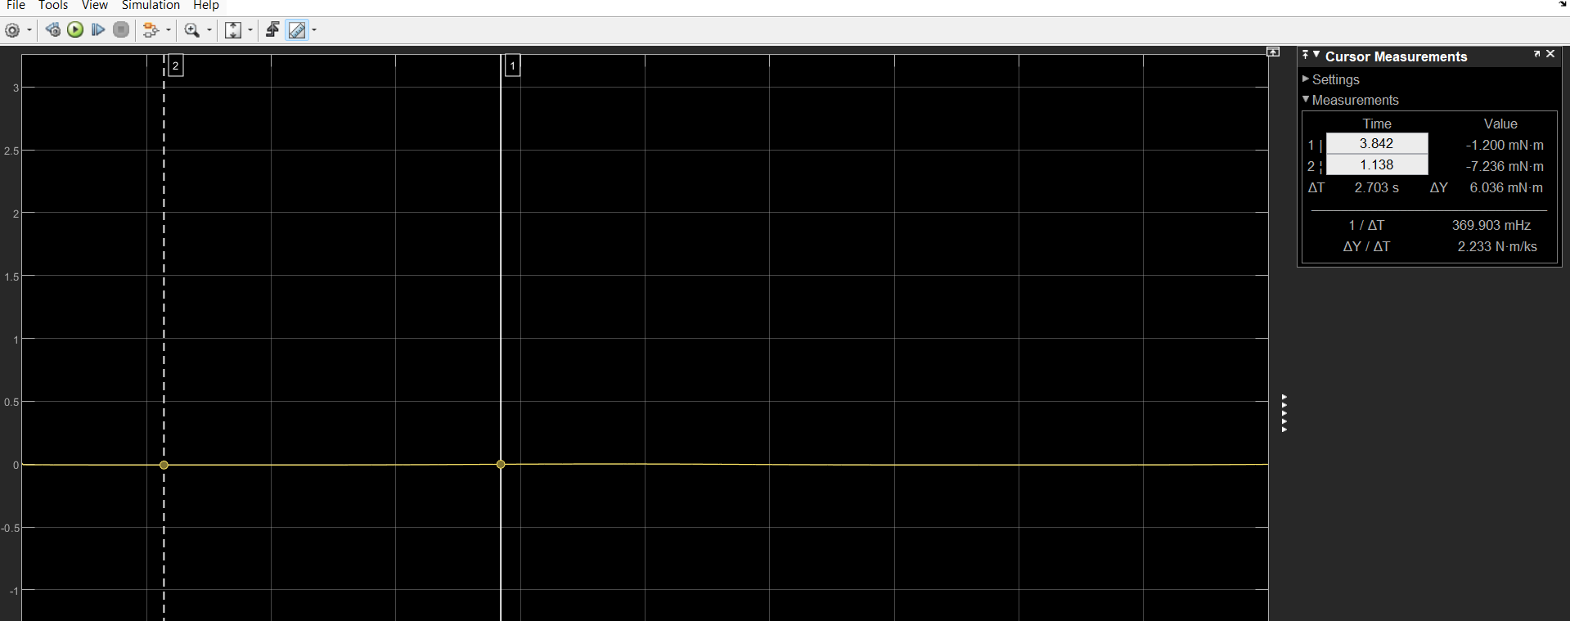
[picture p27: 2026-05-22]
matlab files/motor_5.png

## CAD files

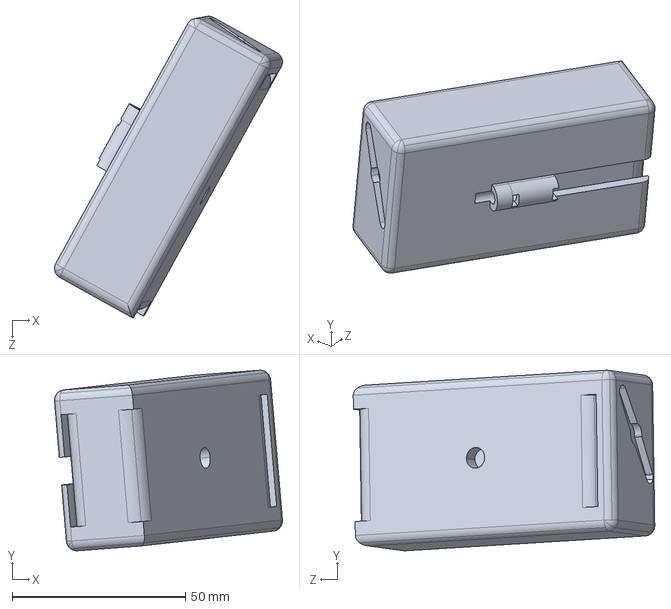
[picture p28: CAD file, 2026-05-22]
matlab files/End_effector_2_Default_sldprt.STEP
65.7 x 52.1 x 87.0 mm

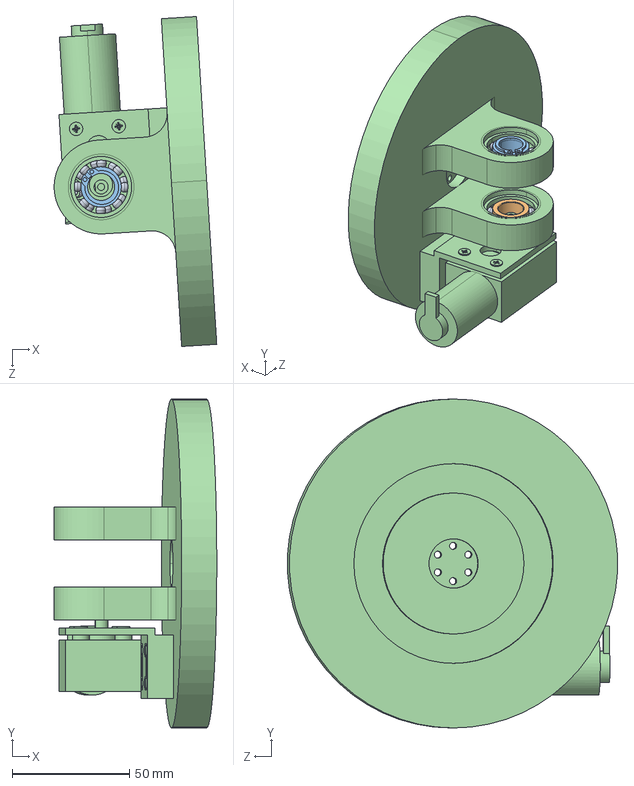
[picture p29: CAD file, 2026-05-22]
simplifide for urdf/rotataing_plata_2 22222222222.STEP
69.2 x 140.0 x 140.5 mm

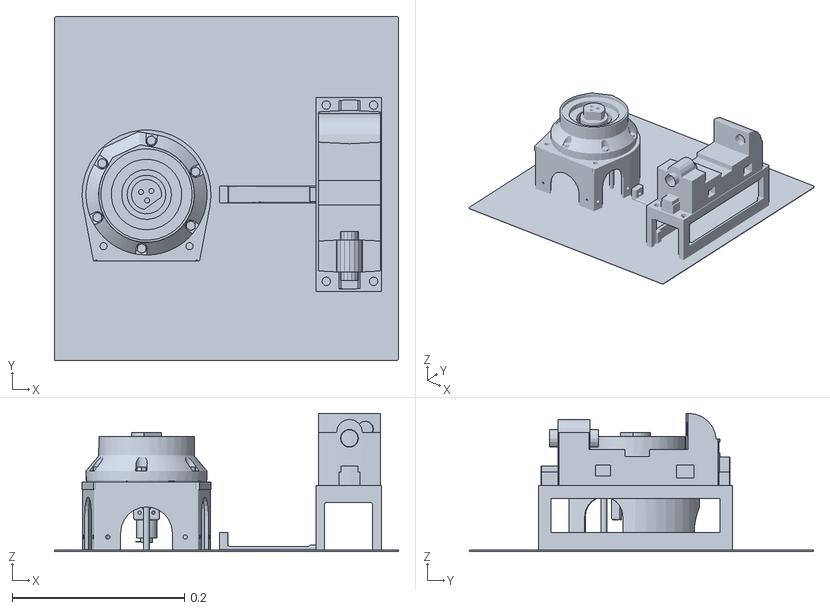
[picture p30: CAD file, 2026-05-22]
simplifide for urdf/urdf/All_robot/meshes/base_link.STL
0.4 x 0.4 x 0.161

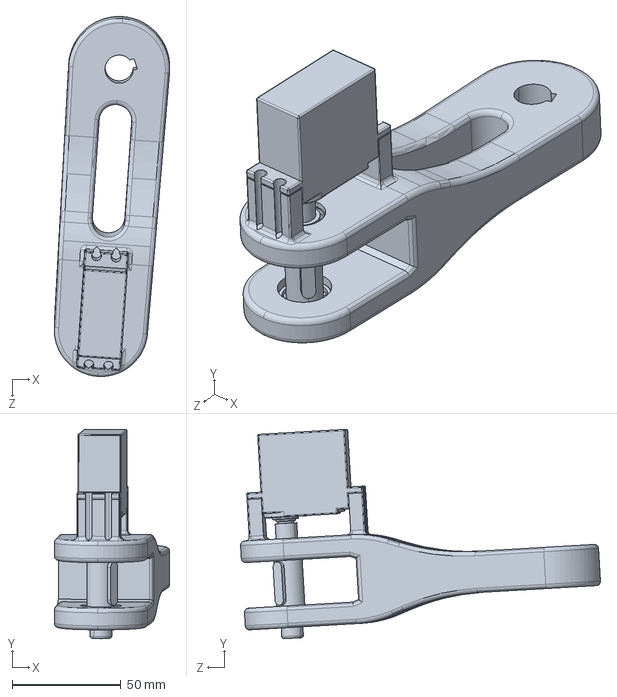
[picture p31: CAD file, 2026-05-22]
matlab files/Arm_2_Default_sldprt.STEP
53.1 x 96.4 x 165.7 mm

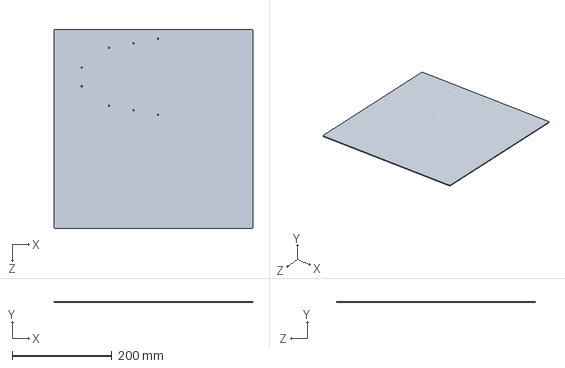
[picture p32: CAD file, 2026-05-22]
simplifide for urdf/plate.SLDPRT
400.0 x 2.00 x 400.0 mm

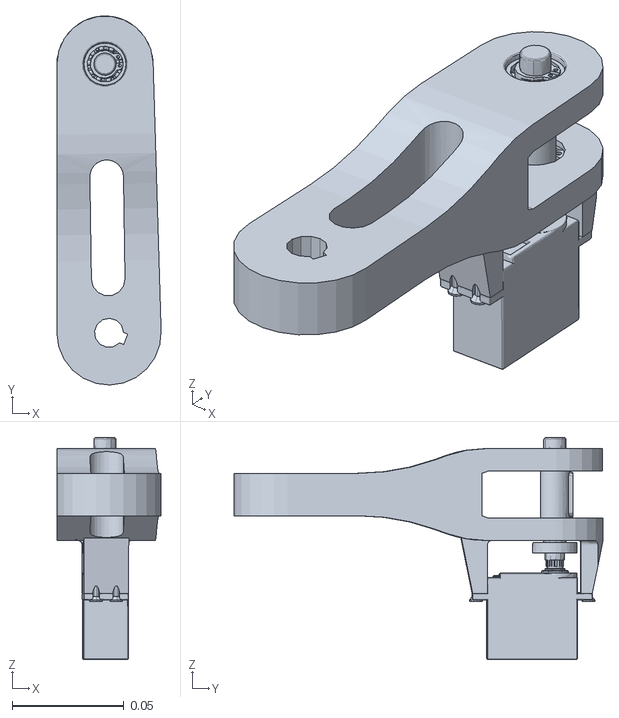
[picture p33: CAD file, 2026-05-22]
simplifide for urdf/urdf/All_robot/meshes/l2.STL
0.0466 x 0.165 x 0.0992

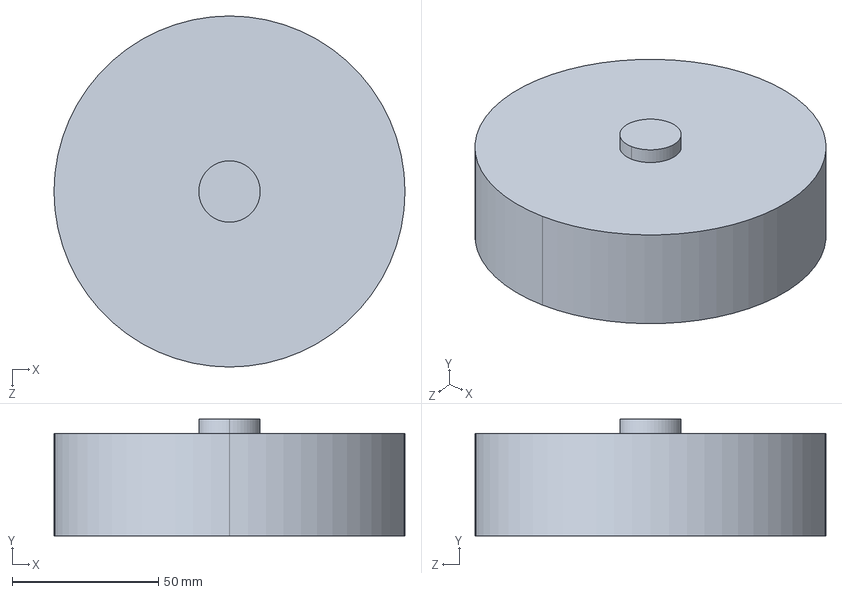
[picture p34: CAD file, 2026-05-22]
matlab files/Part9_Default_sldprt.STEP
120.0 x 40.0 x 120.0 mm

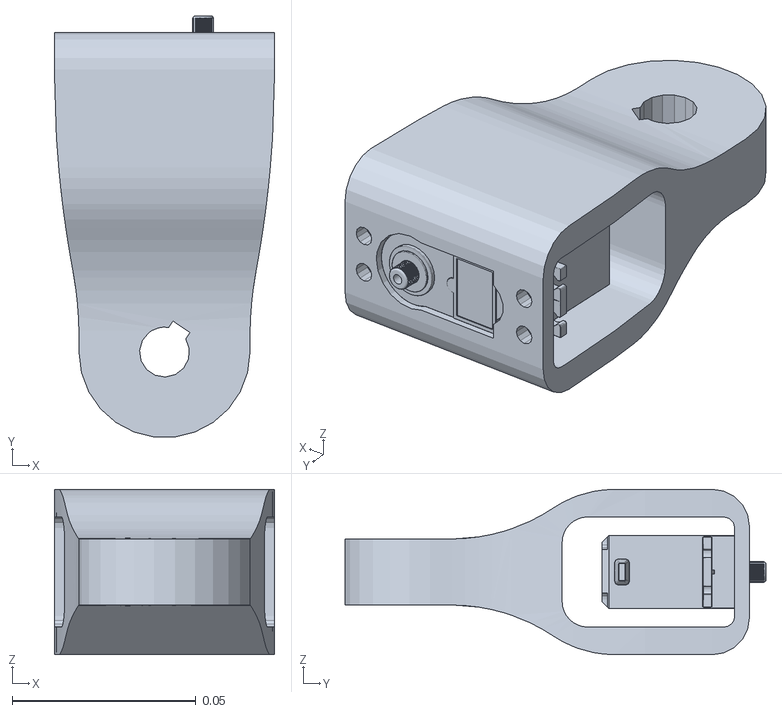
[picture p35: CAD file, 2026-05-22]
simplifide for urdf/urdf/All_robot/meshes/l3.STL
0.06 x 0.115 x 0.045

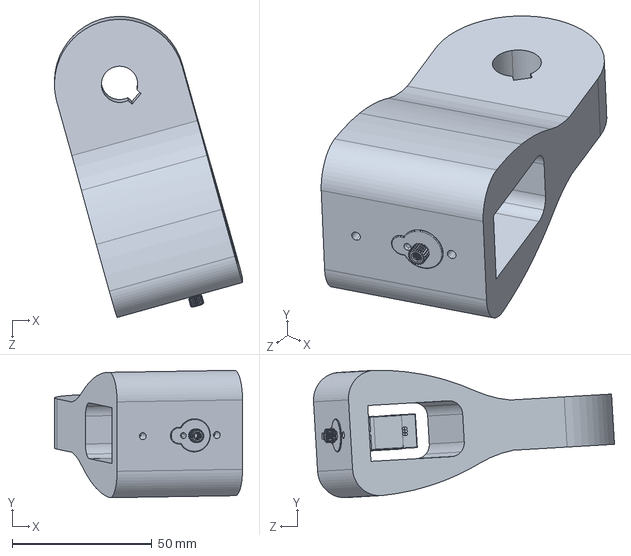
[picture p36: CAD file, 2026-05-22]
matlab files/Arm_3_Default_sldprt.STEP
67.3 x 45.6 x 107.6 mm

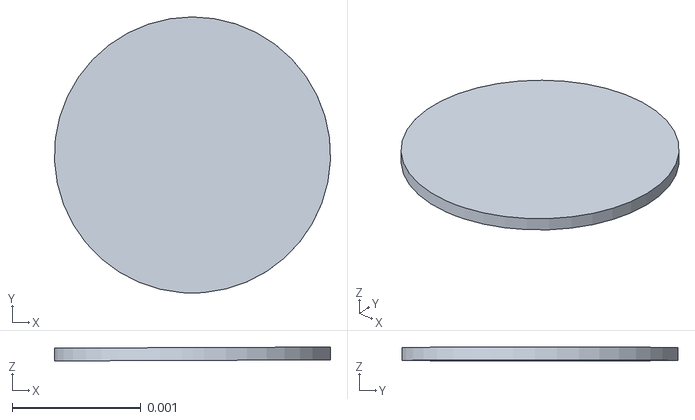
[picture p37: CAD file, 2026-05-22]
simplifide for urdf/urdf/All_robot/meshes/camera.STL
0.00215 x 0.00215 x 0.000108

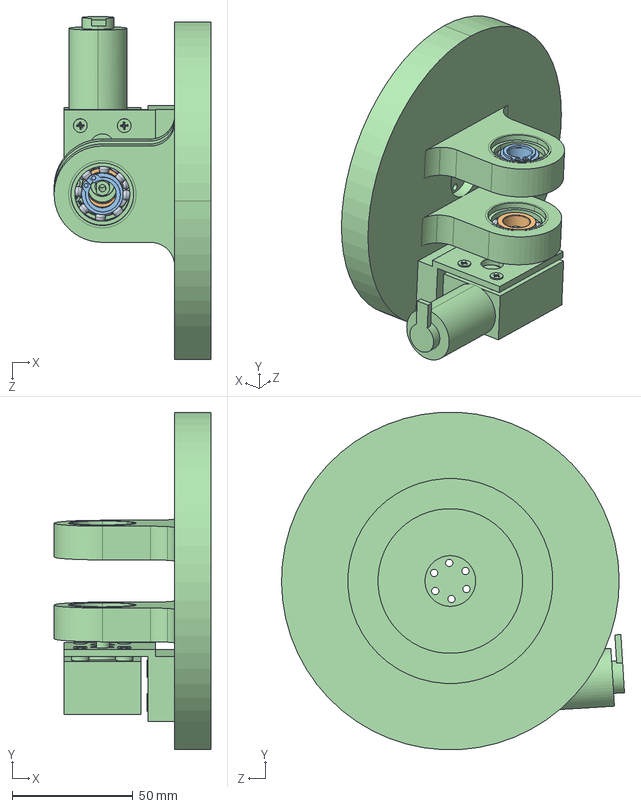
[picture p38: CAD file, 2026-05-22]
matlab files/rotataing_plata_2_Default_sldprt.STEP
65.0 x 139.8 x 142.2 mm

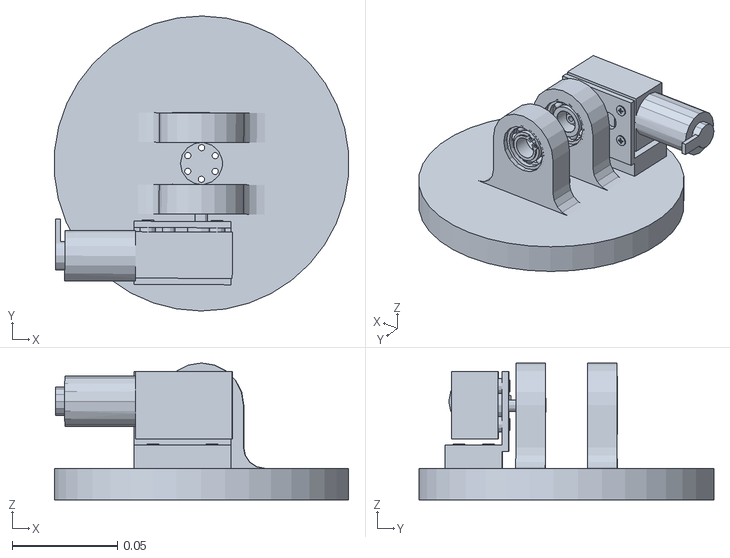
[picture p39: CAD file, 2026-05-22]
simplifide for urdf/urdf/All_robot/meshes/rot.STL
0.14 x 0.14 x 0.065

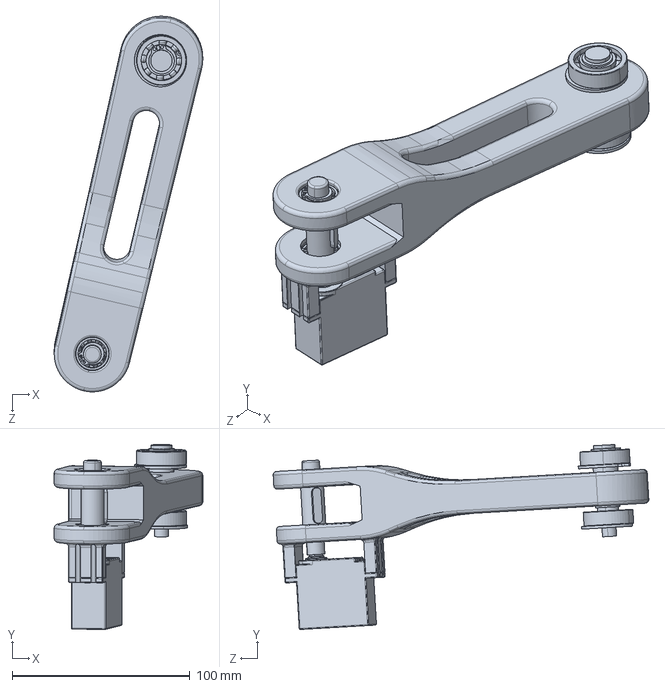
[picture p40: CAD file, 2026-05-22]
matlab files/Arm_1_Default_sldprt.STEP
83.6 x 104.1 x 211.4 mm

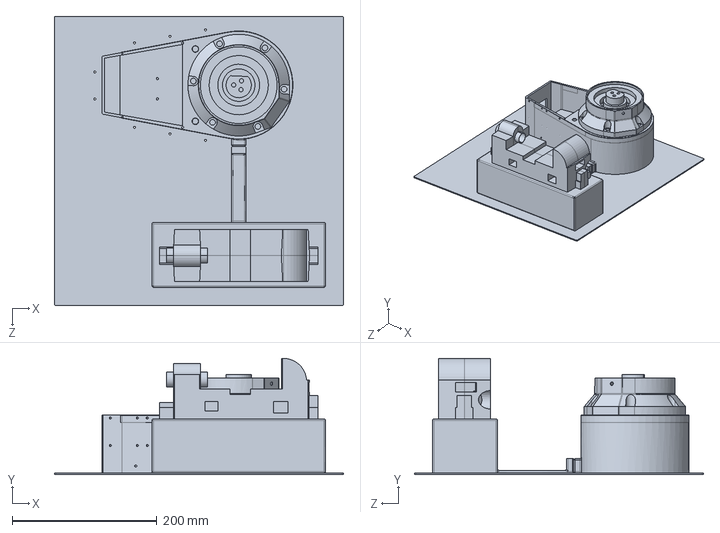
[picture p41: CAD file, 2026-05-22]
simplifide for urdf/final_defeature.SLDPRT
400.0 x 160.8 x 400.0 mm

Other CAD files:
simplifide for urdf/All_robot.SLDASM
simplifide for urdf/final.SLDASM
simplifide for urdf/casting pattern.SLDASM
simplifide for urdf/End_effector_2.SLDPRT
FINAL MECHANICA DESIGN/ANSI B18.2.4.2M - M6x1 - 10.ipt
FINAL MECHANICA DESIGN/AS 1110 - M6 x 20.ipt
FINAL MECHANICA DESIGN/AS 1111 - M6 x 30.ipt
FINAL MECHANICA DESIGN/AS 1427 - M2.5 x 12(5) I.ipt
FINAL MECHANICA DESIGN/Arduino_Mega.ipt
FINAL MECHANICA DESIGN/BASE.ipt
FINAL MECHANICA DESIGN/BS 292 Part 1 - 6001 - 12 x 28 x 8.ipt
FINAL MECHANICA DESIGN/BS 4174 - Type AB. No. 4 x 13 mm(1).ipt
FINAL MECHANICA DESIGN/BS 4174 - Type AB. No. 4 x 19 mm(1).ipt
FINAL MECHANICA DESIGN/BS 4174 - Type AB. No. 4 x 25 mm(1).ipt
FINAL MECHANICA DESIGN/BS 4183 - M2.5 x 5(1) I.ipt
FINAL MECHANICA DESIGN/BS 4183 - M3 x 10(1) I.ipt
FINAL MECHANICA DESIGN/BS 4183 - M3 x 7(1) I.ipt
FINAL MECHANICA DESIGN/BS 4183 - M3 x 8(1) I.ipt
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

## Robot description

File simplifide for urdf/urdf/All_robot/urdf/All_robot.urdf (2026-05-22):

<?xml version="1.0" encoding="utf-8"?>
<!-- This URDF was automatically created by SolidWorks to URDF Exporter! Originally created by Stephen Brawner (brawner@gmail.com) 
     Commit Version: 1.6.0-4-g7f85cfe  Build Version: 1.6.7995.38578
     For more information, please see http://wiki.ros.org/sw_urdf_exporter -->
<robot name="All_robot">
  <link name="base_link">
    <inertial>
      <origin xyz="0.01917 -0.0051557 0.072981" rpy="0 0 0" />
      <mass value="1.9889" />
      <inertia ixx="0.0095683" ixy="-1.8258E-06" ixz="-4.3234E-05" iyy="0.0066241" iyz="-5.4472E-05" izz="0.014977" />
    </inertial>
    <visual>
      <origin xyz="0 0 0" rpy="0 0 0" />
      <geometry>
        <mesh filename="package://All_robot/meshes/base_link.STL" />
      </geometry>
      <material name="">
        <color rgba="1 1 1 1" />
      </material>
    </visual>
    <collision>
      <origin xyz="0 0 0" rpy="0 0 0" />
      <geometry>
        <mesh filename="package://All_robot/meshes/base_link.STL" />
      </geometry>
    </collision>
  </link>
  <link name="rot">
    <inertial>
      <origin xyz="-0.003788 -0.0087997 0.010667" rpy="0 0 0" />
      <mass value="0.203" />
      <inertia ixx="0.00029862" ixy="-2.6283E-05" ixz="1.9741E-05" iyy="0.00026312" iyz="3.9872E-05" izz="0.00044847" />
    </inertial>
    <visual>
      <origin xyz="0 0 0" rpy="0 0 0" />
      <geometry>
        <mesh filename="package://All_robot/meshes/rot.STL" />
      </geometry>
      <material name="">
        <color rgba="0 0 0 1" />
      </material>
    </visual>
    <collision>
      <origin xyz="0 0 0" rpy="0 0 0" />
      <geometry>
        <mesh filename="package://All_robot/meshes/rot.STL" />
      </geometry>
    </collision>
  </link>
  <joint name="rot_joint" type="continuous">
    <origin xyz="-0.092999 -0.0069989 0.1408" rpy="0 0 0" />
    <parent link="base_link" />
    <child link="rot" />
    <axis xyz="0 0 -1" />
    <limit lower="0" upper="0" effort="0" velocity="0" />
  </joint>
  <link name="l1">
    <inertial>
      <origin xyz="-0.0010679 0.10179 0.0089633" rpy="0 0 0" />
      <mass value="0.1376" />
      <inertia ixx="0.00060328" ixy="5.3942E-06" ixz="7.6062E-07" iyy="8.7712E-05" iyz="-7.2206E-05" izz="0.0005571" />
    </inertial>
    <visual>
      <origin xyz="0 0 0" rpy="0 0 0" />
      <geometry>
        <mesh filename="package://All_robot/meshes/l1.STL" />
      </geometry>
      <material name="">
        <color rgba="0 0 1 1" />
      </material>
    </visual>
    <collision>
      <origin xyz="0 0 0" rpy="0 0 0" />
      <geometry>
        <mesh filename="package://All_robot/meshes/l1.STL" />
      </geometry>
    </collision>
  </link>
  <joint name="l1_joint" type="revolute">
    <origin xyz="0 -0.0005 0.0375" rpy="1.5708 0 -0.0039085" />
    <parent link="rot" />
    <child link="l1" />
    <axis xyz="0 0 1" />
    <limit lower="-1.57" upper="1.57" effort="0" velocity="0" />
  </joint>
  <link name="l2">
    <inertial>
      <origin xyz="-0.0011197 0.074655 -0.011196" rpy="0 0 0" />
      <mass value="0.11046" />
      <inertia ixx="0.00027612" ixy="2.8913E-06" ixz="-6.4454E-07" iyy="7.8927E-05" iyz="4.3574E-05" izz="0.0002299" />
    </inertial>
    <visual>
      <origin xyz="0 0 0" rpy="0 0 0" />
      <geometry>
        <mesh filename="package://All_robot/meshes/l2.STL" />
      </geometry>
      <material name="">
        <color rgba="0 1 0 1" />
      </material>
    </visual>
    <collision>
      <origin xyz="0 0 0" rpy="0 0 0" />
      <geometry>
        <mesh filename="package://All_robot/meshes/l2.STL" />
      </geometry>
    </collision>
  </link>
  <joint name="l2_joint" type="revolute">
    <origin xyz="-0.001789 0.16999 0" rpy="0 0 0" />
    <parent link="l1" />
    <child link="l2" />
    <axis xyz="0 0 1" />
    <limit lower="-1.92" upper="1.92" effort="0" velocity="0" />
  </joint>
  <link name="l3">
    <inertial>
      <origin xyz="-1.0589E-05 0.043229 -0.00099981" rpy="0 0 0" />
      <mass value="0.13434" />
      <inertia ixx="0.00011138" ixy="2.0552E-07" ixz="8.7349E-12" iyy="4.8295E-05" iyz="4.3329E-10" izz="0.000122" />
    </inertial>
    <visual>
      <origin xyz="0 0 0" rpy="0 0 0" />
      <geometry>
        <mesh filename="package://All_robot/meshes/l3.STL" />
      </geometry>
      <material name="">
        <color rgba="1 0 0 1" />
      </material>
    </visual>
    <collision>
      <origin xyz="0 0 0" rpy="0 0 0" />
      <geometry>
        <mesh filename="package://All_robot/meshes/l3.STL" />
      </geometry>
    </collision>
  </link>
  <joint name="l3_joint" type="revolute">
    <origin xyz="-0.001789 0.11999 0" rpy="0 0 0" />
    <parent link="l2" />
    <child link="l3" />
    <axis xyz="0 0 1" />
    <limit lower="-1.74" upper="1.74" effort="0" velocity="0" />
  </joint>
  <link name="l4">
    <inertial>
      <origin xyz="0.0010378 -0.0056914 0.050171" rpy="0 0 0" />
      <mass value="0.10668" />
      <inertia ixx="8.126E-05" ixy="-4.6534E-08" ixz="-2.7201E-07" iyy="6.8474E-05" iyz="-8.97E-08" izz="2.55E-05" />
    </inertial>
    <visual>
      <origin xyz="0 0 0" rpy="0 0 0" />
      <geometry>
        <mesh filename="package://All_robot/meshes/l4.STL" />
      </geometry>
      <material name="">
        <color rgba="0.7 0.7 1 1" />
      </material>
    </visual>
    <collision>
      <origin xyz="0 0 0" rpy="0 0 0" />
      <geometry>
        <mesh filename="package://All_robot/meshes/l4.STL" />
      </geometry>
    </collision>
  </link>
  <joint name="l4_joint" type="continuous">
    <origin xyz="0.010507 0.085905 -0.0013063" rpy="-1.5708 0.0039085 0" />
    <parent link="l3" />
    <child link="l4" />
    <axis xyz="0 0 -1" />
    <limit lower="0" upper="0" effort="0" velocity="0" />
  </joint>
  <link name="camera">
    <inertial>
      <origin xyz="-1.3399E-12 -1.0925E-13 3.2725E-12" rpy="0 0 0" />
      <mass value="3.6262E-07" />
      <inertia ixx="1.0494E-13" ixy="1.2313E-26" ixz="-4.0779E-16" iyy="1.0494E-13" iyz="-3.1502E-24" izz="2.0927E-13" />
    </inertial>
    <visual>
      <origin xyz="0 0 0" rpy="0 0 0" />
      <geometry>
        <mesh filename="package://All_robot/meshes/camera.STL" />
      </geometry>
      <material name="">
        <color rgba="0 0 0 1" />
      </material>
    </visual>
    <collision>
      <origin xyz="0 0 0" rpy="0 0 0" />
      <geometry>
        <mesh filename="package://All_robot/meshes/camera.STL" />
      </geometry>
    </collision>
  </link>
  <joint name="camera_joint" type="fixed">
    <origin xyz="0.014456 -0.0057379 0.052805" rpy="1.5708 0 1.5708" />
    <parent link="l4" />
    <child link="camera" />
    <axis xyz="0 0 0" />
  </joint>
</robot>
